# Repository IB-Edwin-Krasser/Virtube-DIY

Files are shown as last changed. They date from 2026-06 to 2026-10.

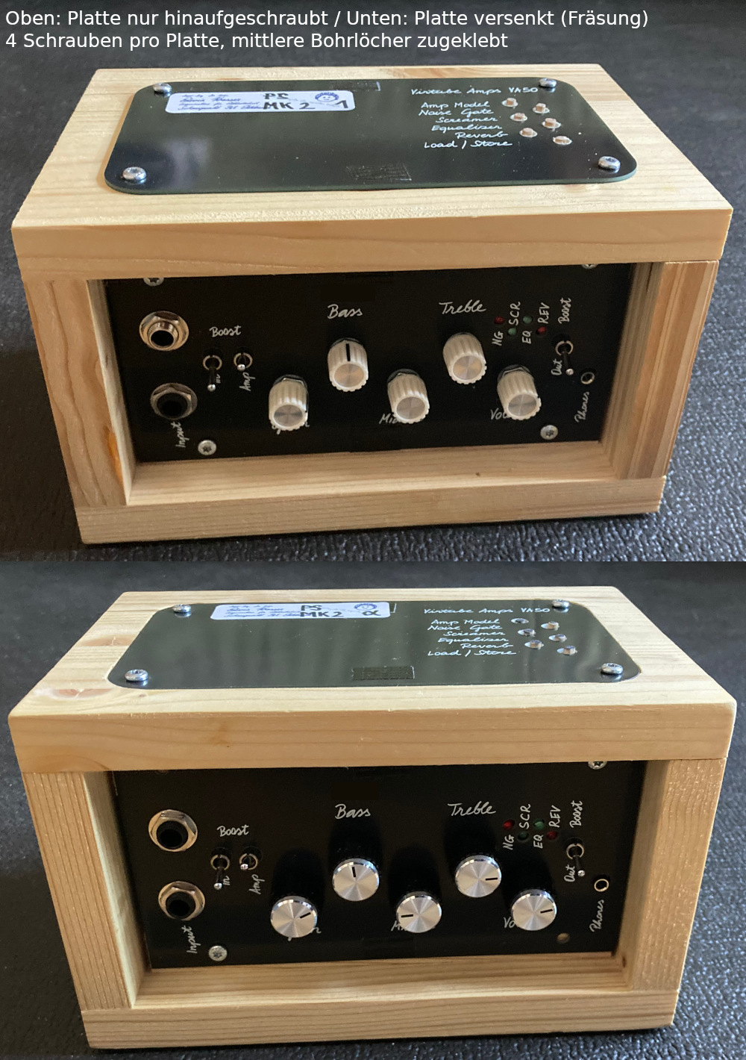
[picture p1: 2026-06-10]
fertigungsdaten/Foto2-Prototyp.JPG

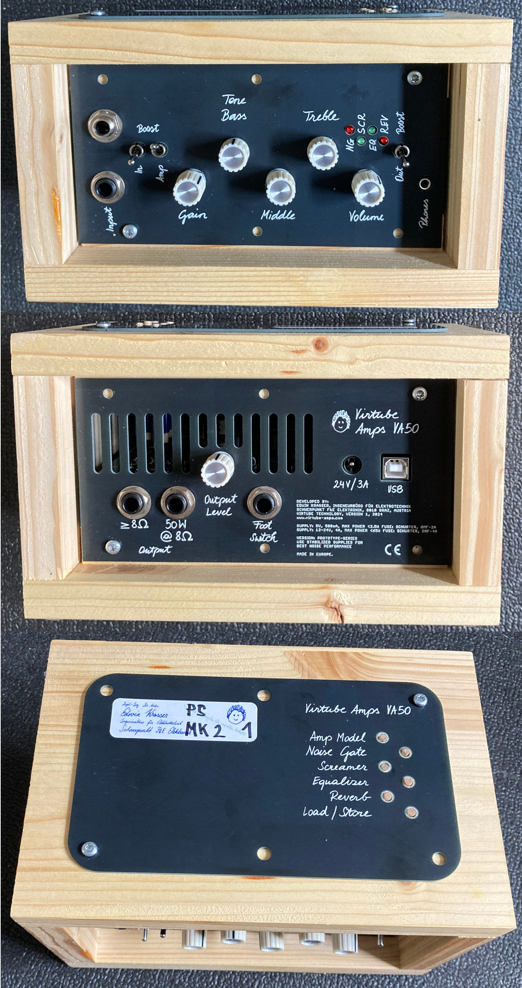
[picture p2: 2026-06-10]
fertigungsdaten/Foto1-Prototyp.JPG

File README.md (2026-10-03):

## readme.md: Virtube-DIY

AmpLightFront

"Virtube Amps VA50" – Virtueller Vollröhrenverstärker: So habe ich das "Kastl" genannt. Nun gebe ich die Fertigunsdaten der Hardware sowie das Software-Grundgerüst frei.

* ./brd: Schaltplan, Layout und Eagle-BRD-Datei.

* ./fertigungsdaten: Fertigungsdaten für Hauptprint und den Blenden, diverse Beschreibungen und Anleitungen.  
  *Anmerkung: Das so gefertigte Gerät ist von einem akkreditierten Testlabor auf alle CE-notwendigen Eigenschaften erfolgreich getestet worden.*

* ./Virtube-DIY: Code Composer Studio Projekt.
    * Framework und Treiber, jeder kann seinen Verstärker selbst programmieren.
    * Das gesamte Software-Framework ist Doxygen-dokumentiert.
    * Die Simulationen und Berechnungen der virtuellen Verstärker sind nicht Teil der Veröffentlichung.
    * Die vier Effekte (Noise Gate, Tube Screamer, Equalizer, Reverb) sind dabei, sowie die virtuelle Röhrenberechnung (mit einer Beispielberechnung in "amps.c"), viel Spaß damit!
    * Library-Dateien von TI sind aus lizenzrechtlicher Vorsicht nicht dabei, sehrwohl aber ein Verzeichnisbaum mit den benötigten Dateien (C2000Ware). Siehe: https://e2e.ti.com/support/microcontrollers/c2000-microcontrollers-group/c2000/f/c2000-microcontrollers-forum/1654050/tms320f28377s-c2000ware-license-and-public-dist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
    * Code-Stil-Beschreibung: siehe "C-CodingStyle.pdf"

* Lizenzinformationen zur Hardware:
    * CERN Open Hardware Licence Version 2 - Weakly Reciprocal (CERN-OHL-W v2)
    * Copyright © 2025 Edwin Krasser
    * This hardware design is released under the CERN-OHL-W v2 license with the following additional restriction:
    * Commercial use, production, sale, or incorporation into commercial products is explicitly prohibited without prior written permission from the author.
    * Contact Edwin Krasser for commercial licensing.
    * Gerber files, Board files (.brd) and BOM are provided for non-commercial use.
    * Schematic is provided as PDF only (not as editable source).

* Edwin Krasser, Ingenieurbüro für Elektrotechnik, Schwerpunkt F&E Elektronik.
* ib.ekrasser@gmail.com
* www.ib-ekrasser.at
* www.ib-ekrasser.at/virtube

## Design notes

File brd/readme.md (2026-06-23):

## License & Usage

This project is released under the **CERN-OHL-W v2** license with **non-commercial** restriction.

**What you may do:**
- Private use, education, research, non-profit projects
- Modify and build the hardware for yourself
- Share modified versions (under the same license)

**What you may NOT do:**
- Sell boards or kits
- Use the design in commercial products
- Distribute for commercial purposes

Schematic is provided as PDF only.  
Eagle board file (.brd) is provided for non-commercial reproduction.

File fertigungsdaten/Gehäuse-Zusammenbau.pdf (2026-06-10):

Gehäuse - Zusammenbau
1. Benötigte Teile, 18 mm Holz (Fichte)
- 2x 21x14 cm
- 2x 9x14 cm
- 1x 17x10 cm
- 2x 2x17 cm
2. 21x14 cm mit 9x14 cm Seitenteilen und zweimal 2x17 cm im Abstand von 2 cm zur Vorder-/Hinterkante verleimen.

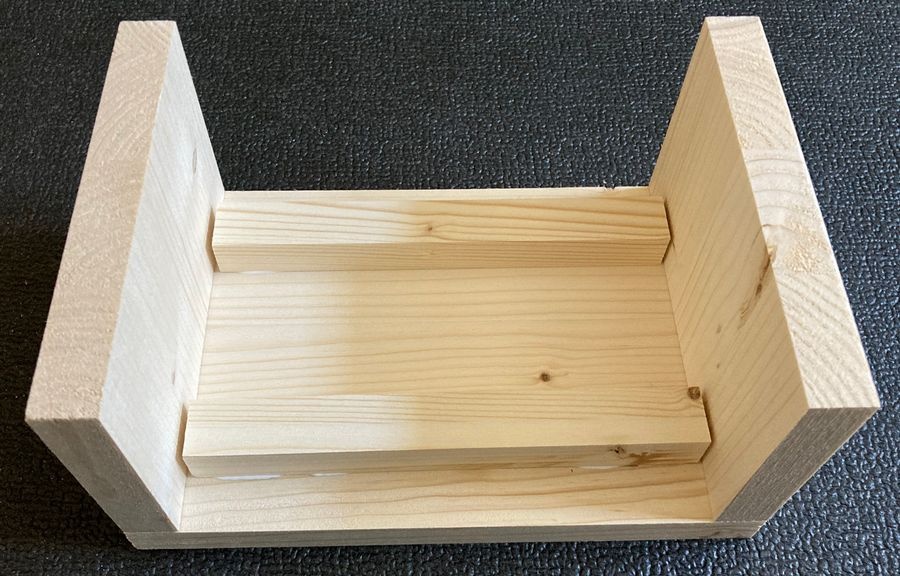
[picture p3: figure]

3. 21x14 cm (oben) fräsen (2 mm, damit die obere Abdeckung genau passt, oder auch nicht), mit 17x10 cm zusammenleimen und bohren

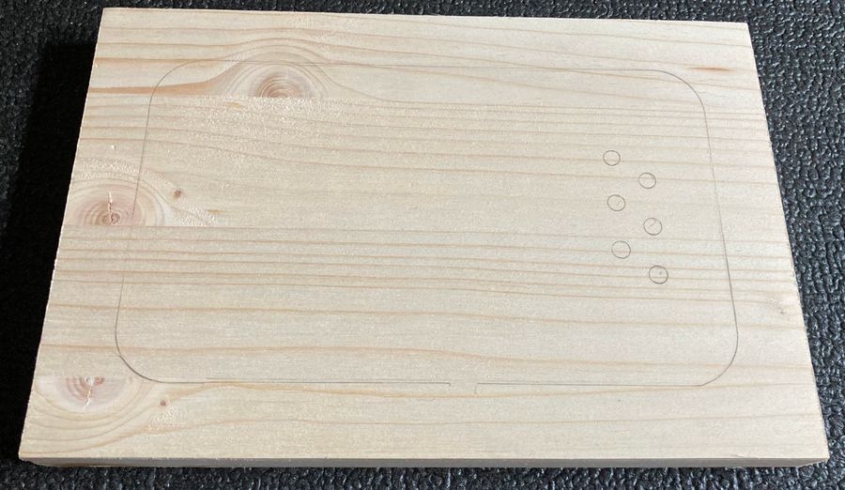
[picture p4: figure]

Hier nur gebohrt (4 mm), Position der Bohrlöcher: 40 bzw. 50 mm rechts, linke Reihe 58.75 mm, 73.75 mm (15 mm weiter), 88.75 (15 mm weiter), rechte Reihe 51.25, 66.25 und 81.25 mm. Bohrung mit gut 4 mm (eher 4.2 mm Bohrer?).

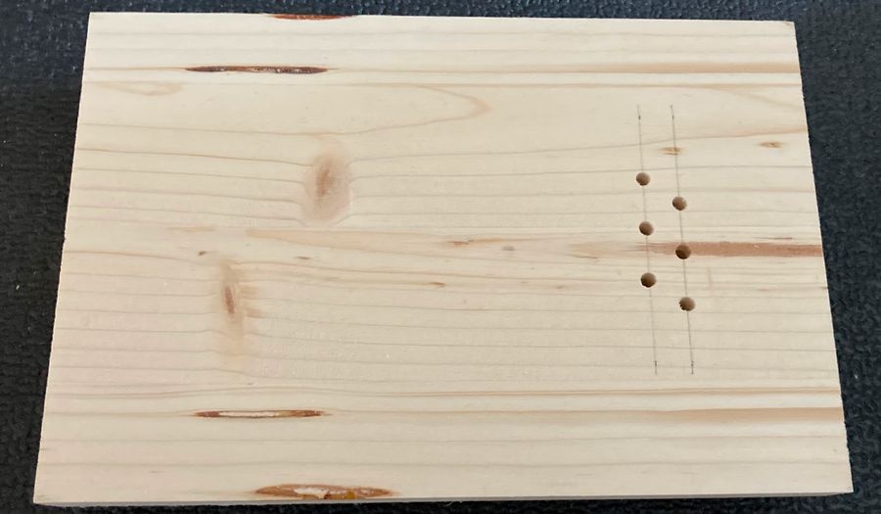
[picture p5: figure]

4. Gehäuse zusammenleimen

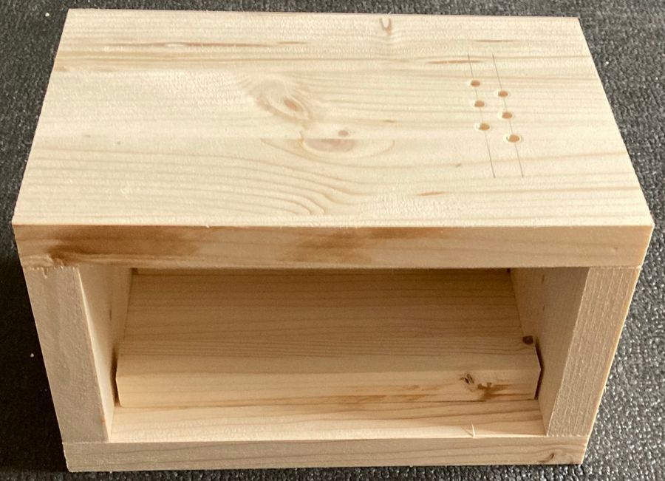
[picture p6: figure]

5. Kanten etwas abrunden? Dann ölen, lackieren oder was auch immer …
6. Stößel aus 4 mm Rundholz und Länge 60 mm (bzw. 62 mm wenn der obere Print hinaufgeschraubt ist) … an den Stößeln mit mindestens 40 mm Abstand von oben eine Verdickung anbringen (hier mit Isolierband)

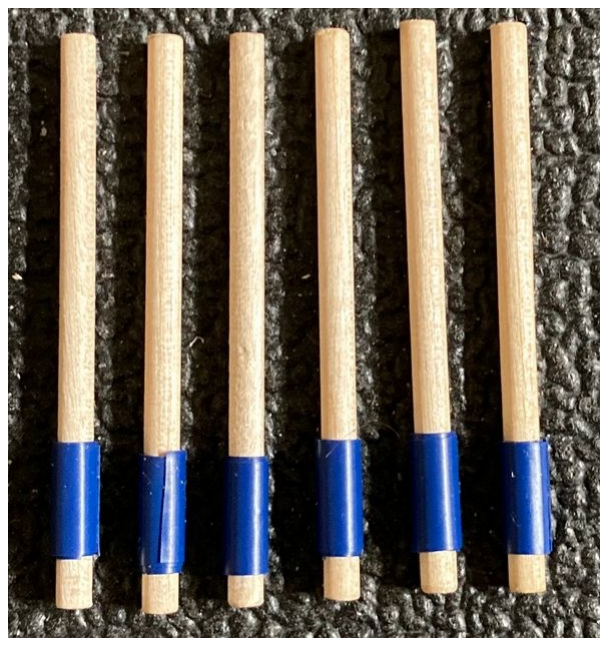
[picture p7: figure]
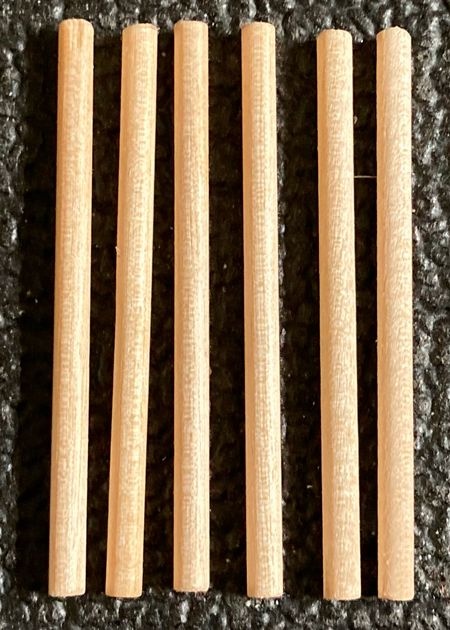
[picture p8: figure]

7. Stößel ins Gehäuse einsetzen, von innen (darum ist unten keine volle Platte, damit sich das mit der Länge der Stößel ausgeht)

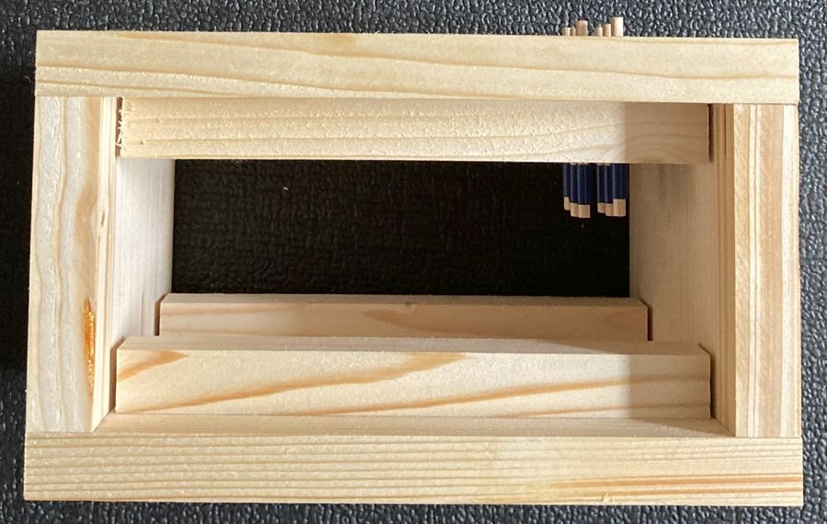
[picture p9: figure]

8. Zusammenbau
- Zuerst Front-Blende mit dem Print verschrauben, dann ins Gehäuse einsetzen …

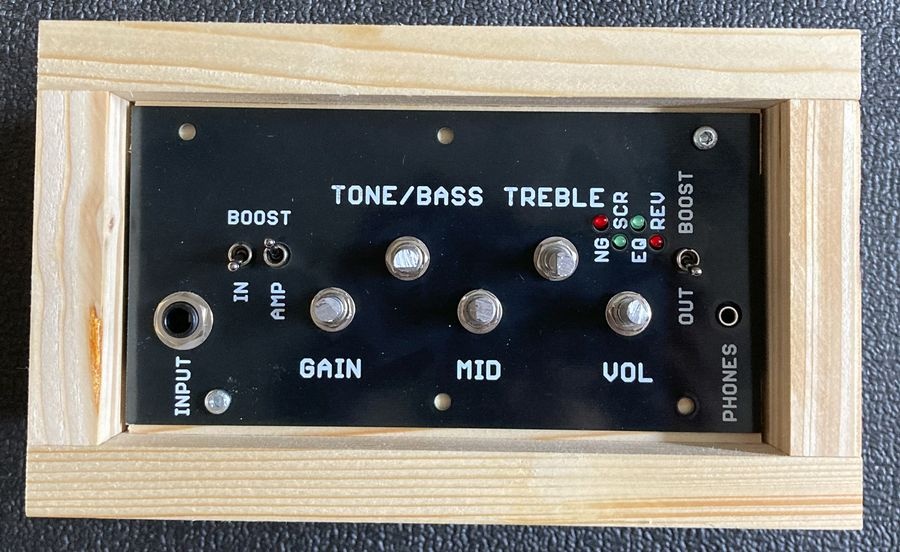
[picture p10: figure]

- Rückseite verschrauben …

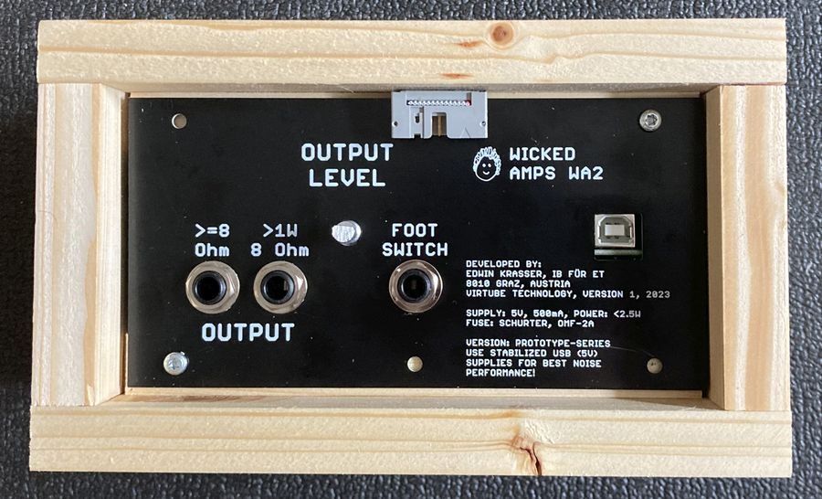
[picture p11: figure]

Anmerkung: Hier (Prototyp) ist auch der Debug-Stecker zu sehen. Der ist später natürlich nicht dabei.

- Obere Abdeckung anschrauben …

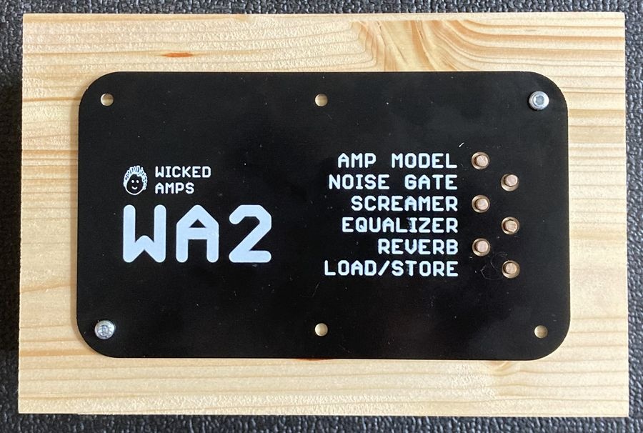
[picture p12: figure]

9. Abschließend: Poti-Knöpfe montieren. Bei den richtigen Potis müssten diese nur hinauf gesteckt werden (Riffelung statt glatt).

Anmerkung: Hier werden (Prototyp) nicht alle Schrauben verwendet, sondern immer nur zwei statt alle sechs. Das macht ein Zerlegen wieder einfacher.

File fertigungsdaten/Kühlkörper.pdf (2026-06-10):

Kühlkörper - Zusammenkleben

### 1. Vorbereitung

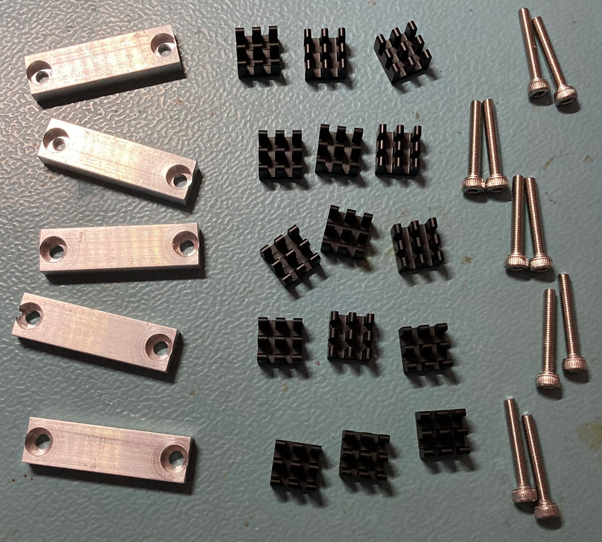
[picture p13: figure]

Pro Kühlkörper:

- Träger-Block
- 2x M3 Zylinderkopf-Schrauben, 20 mm Länge
- 3x 10x10mm Kühlkörper

HSB02-101007

Digi-Key-Teilenr. | 2223-HSB02-101007-ND
Hersteller | CUI Devices (https://www.digikey.at/de/supplier-centers/cui-devices)
Hersteller-
Teilenummer | HSB02-101007
Beschreibung | HEAT SINK, BGA, 10 X 10 X 7 MM

### 2. Zusammenbau

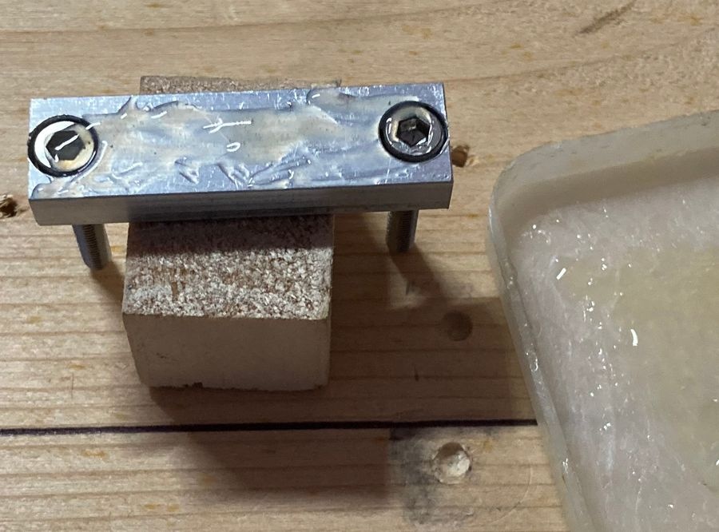
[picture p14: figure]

- Schrauben durchsteckern.

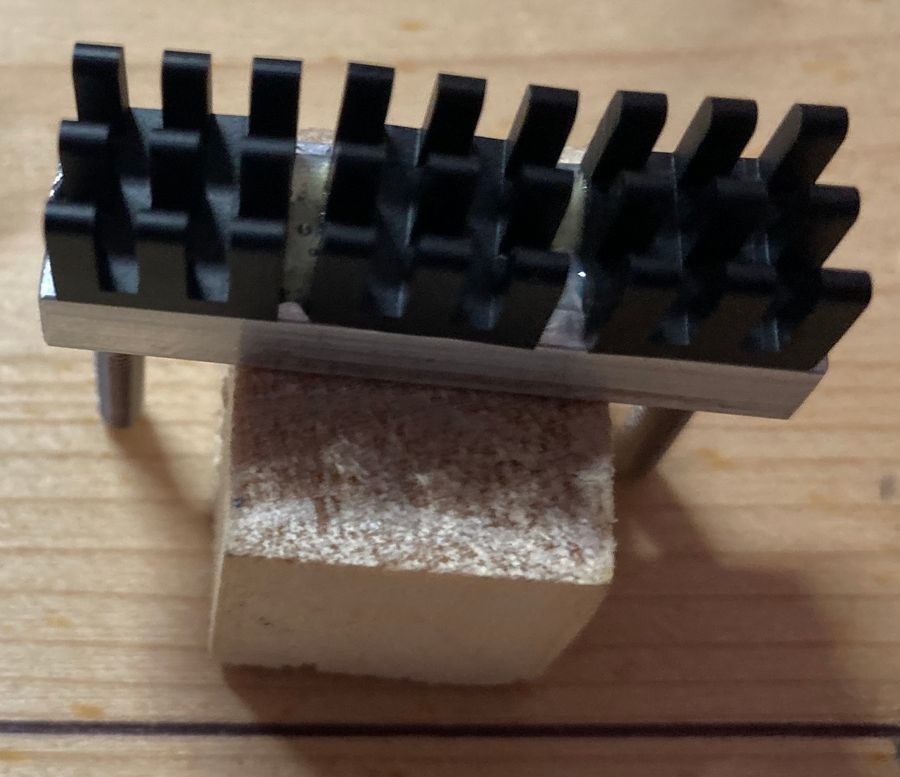
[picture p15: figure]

- Mit UHU Plus (Epoxidharz-Kleber) einstreichen.
- Die drei Kühlkörper aufsetzen.

### 3. Ab ins Backrohr

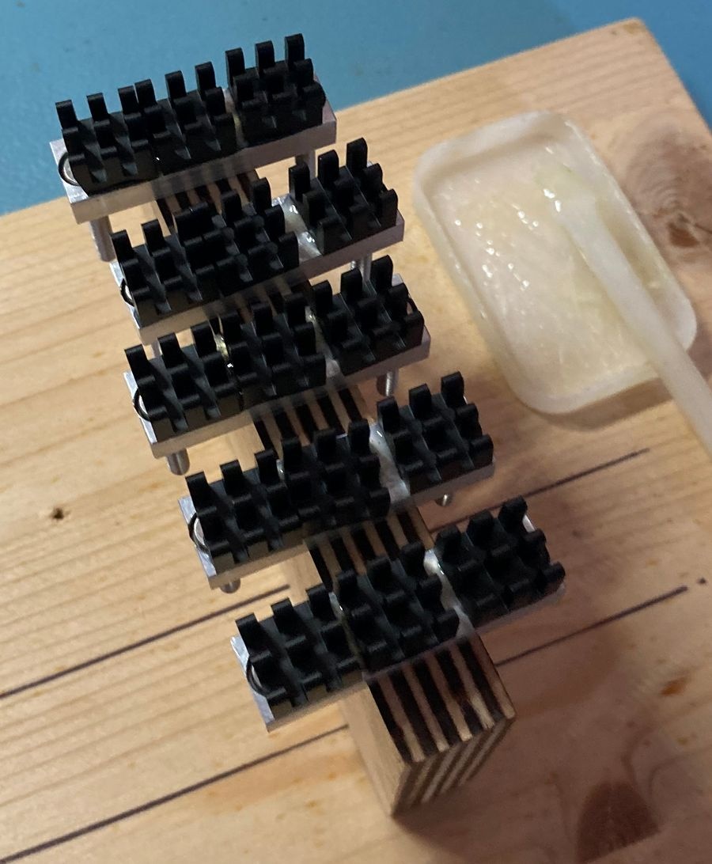
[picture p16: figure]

- Mehrere auf einem Holzstück reihen …
- Ab ins Backrohr: auf 100 °C aufheizen, abschalten, Kühlkörper ins Rohr und 45 Minuten „auskühlen lassen“

Kühlkörper - Einbau

### 1. Wärmeleitschaumstoff aufkleben

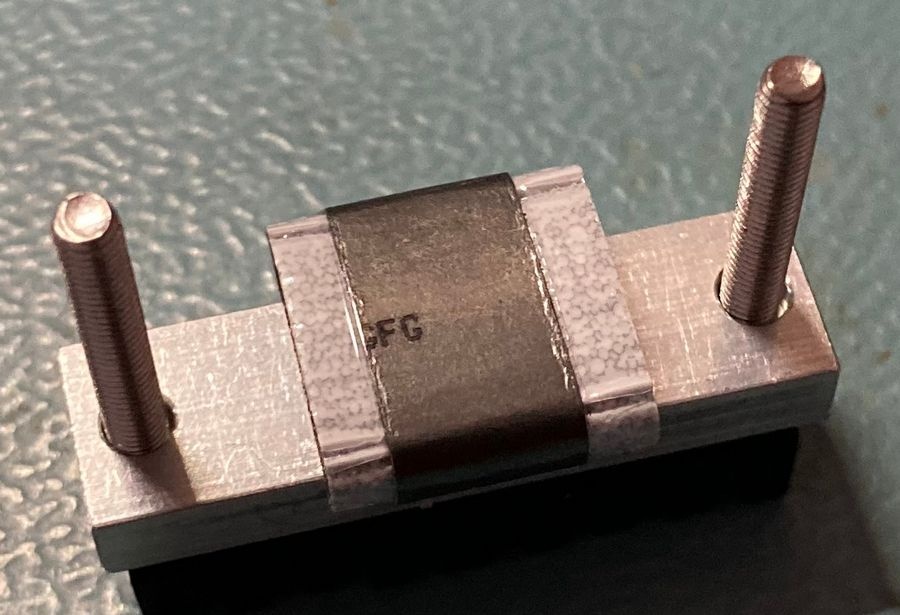
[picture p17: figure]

- Würth Elektronik: WE-TGFG Thermal Graphite Foam Gasket: 407150015050

### 2. Print: Kühlkörper-Schrauben durchstecken

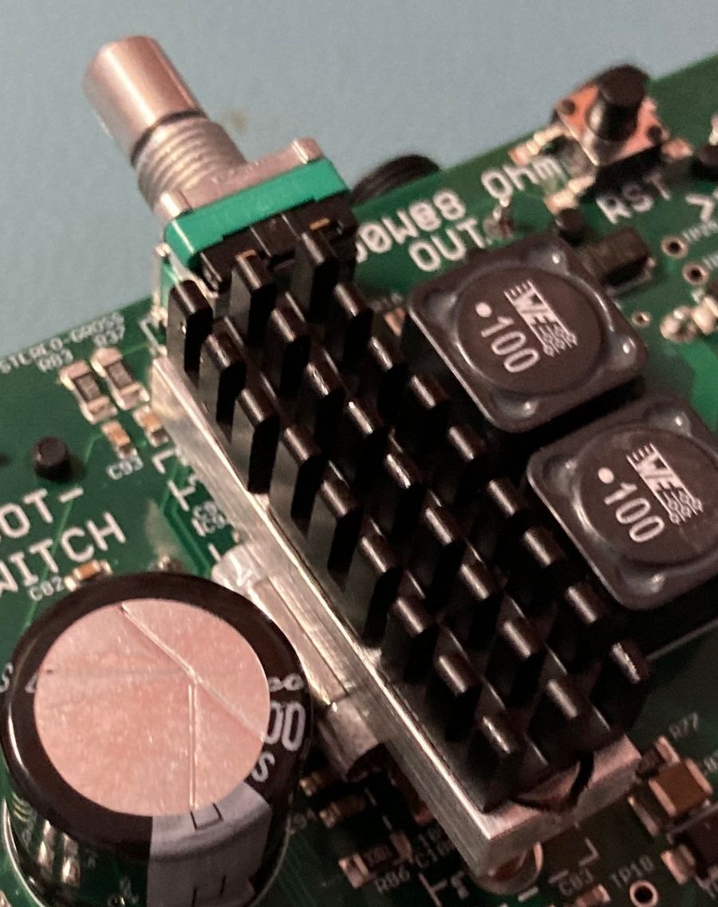
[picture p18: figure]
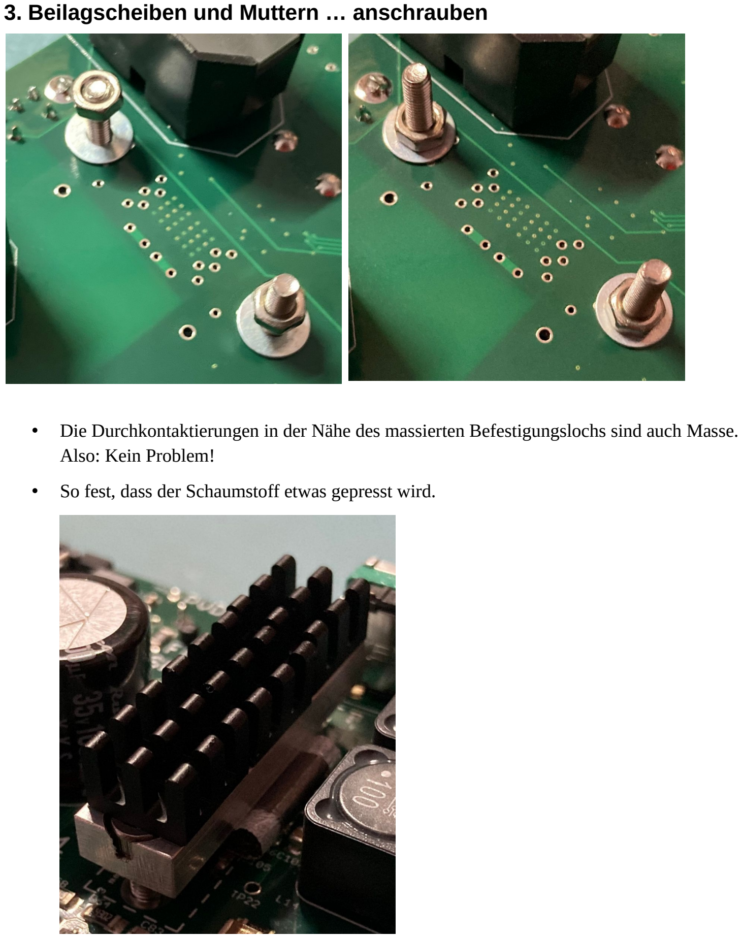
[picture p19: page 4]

### 3. Beilagscheiben und Muttern … anschrauben

- Die Durchkontaktierungen in der Nähe des massierten Befestigungslochs sind auch Masse. Also: Kein Problem!
- So fest, dass der Schaumstoff etwas gepresst wird.

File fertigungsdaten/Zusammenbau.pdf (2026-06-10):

Zusammenbau

### 1. Start: Elektronik – Frontblende – zweite Klinkenbuchse

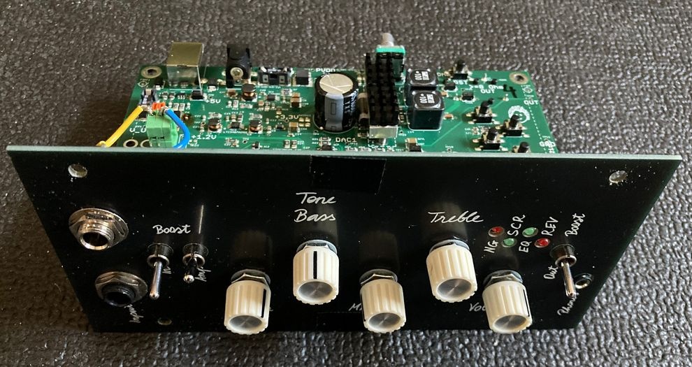
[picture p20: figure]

- Frontblende aufstecken

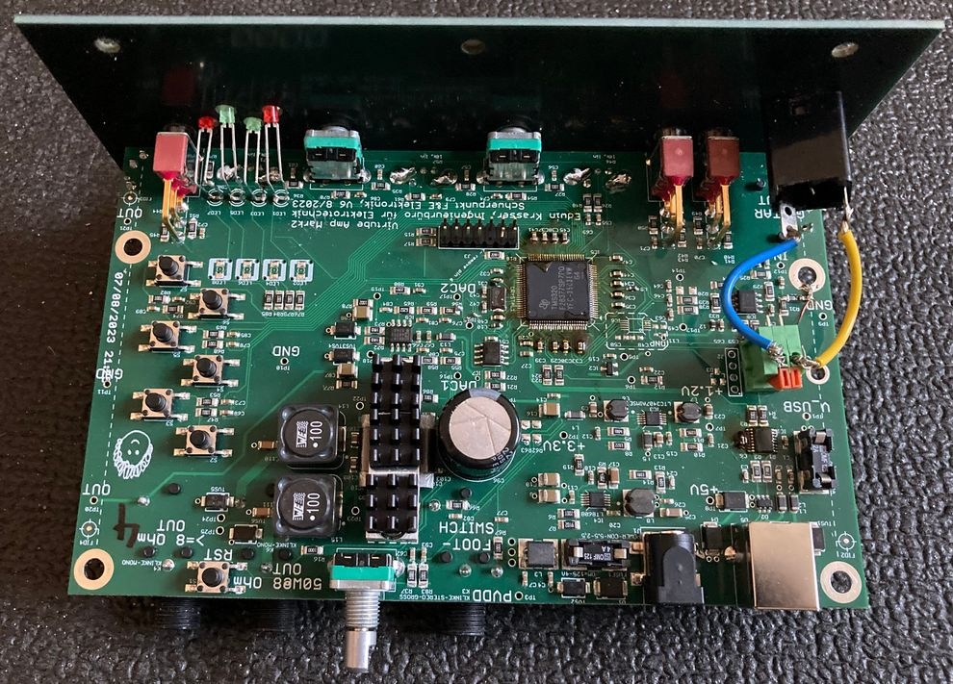
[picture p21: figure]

- Potis mit Beilage/Mutter fixieren (nicht zu fest, da sie etwas vom Rand entfernt sind, ist beim Redesign berichtigt)
- zweite Klinkenbuchse: Switchcraft Inc. 111X, DigiKey-Teilenr. SC2830-ND
- zweite Klinkenbuchse bei der Steckklemme anschließen (wird im Redesign etwas anders ausgerichtet sein, hier ist noch eine Bastellösung eingebaut, dann: näher der Klinkenbuchse/Vorderpanel … Signal, näher Rückwand: Ground).
- Kühlkörper montiert

### 2. Holzgehäuse vorbereiten

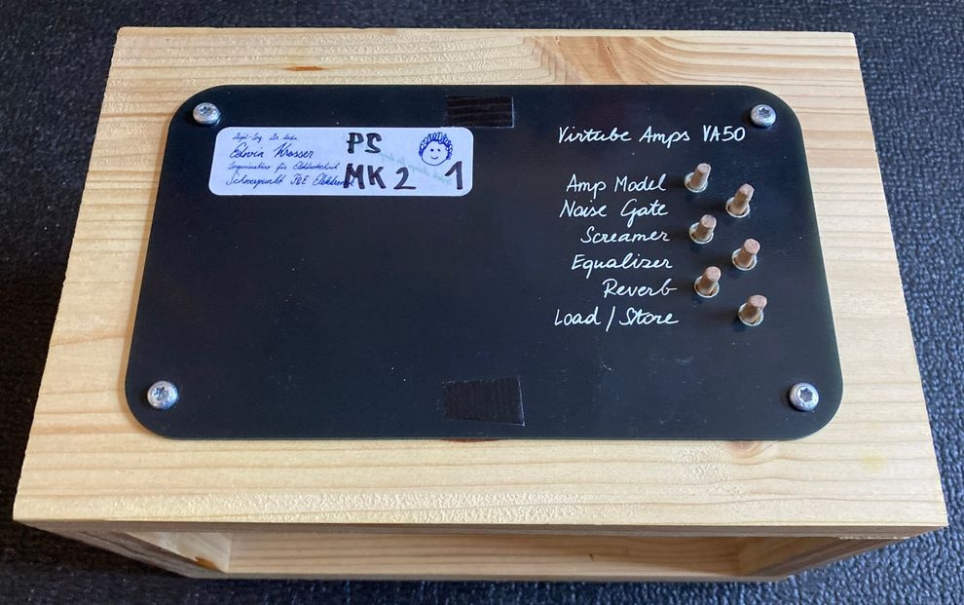
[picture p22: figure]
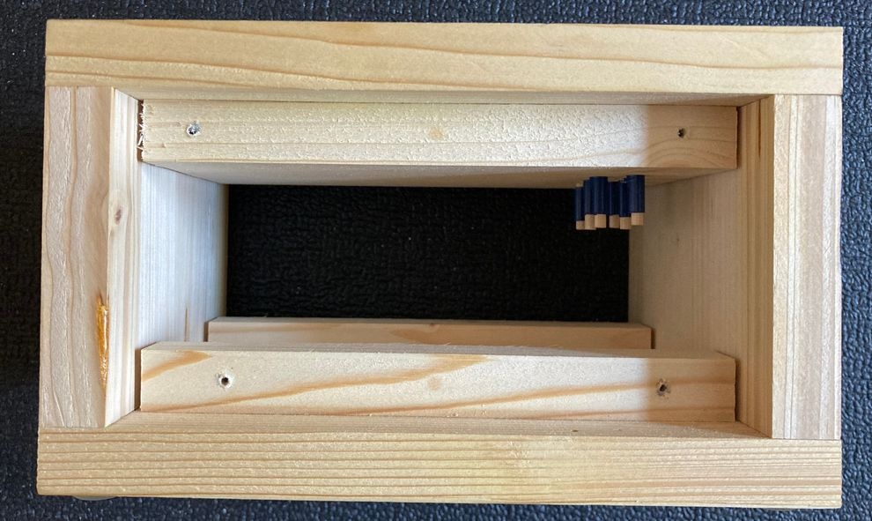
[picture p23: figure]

- Platte oben montieren (den Prototypen-Aufkleber gibt es später natürlich nicht)
- Tasten-Stößel durchstecken und nach oben, sodass sie oben etwas weiter heraus stehen
- Hier wäre es schön, wenn die obere Platte versenkt wäre, also diese 2 mm im Holz ausgefräst werden (wie bei diesem Prototypen).

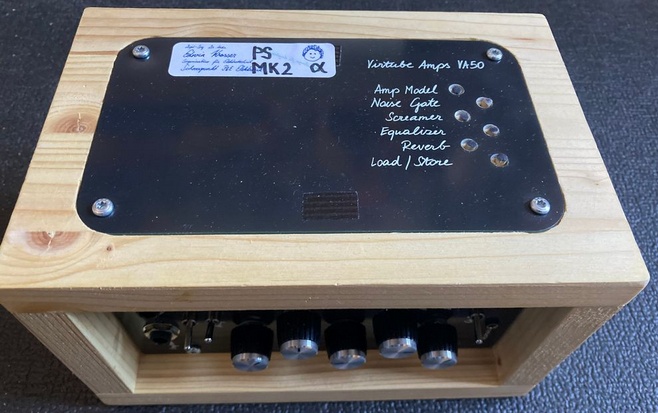
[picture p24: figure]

### 3. Zusammenbauen

- Elektronik mit Front einbauen (vier Schrauben)

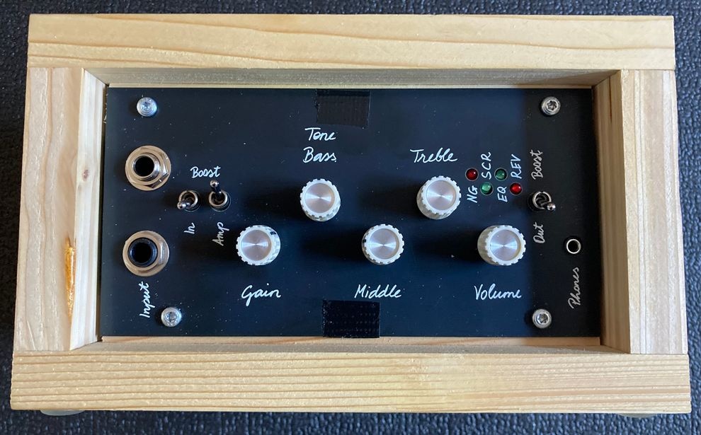
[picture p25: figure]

- Rückblende hinauf stecken, Beilagscheiben …

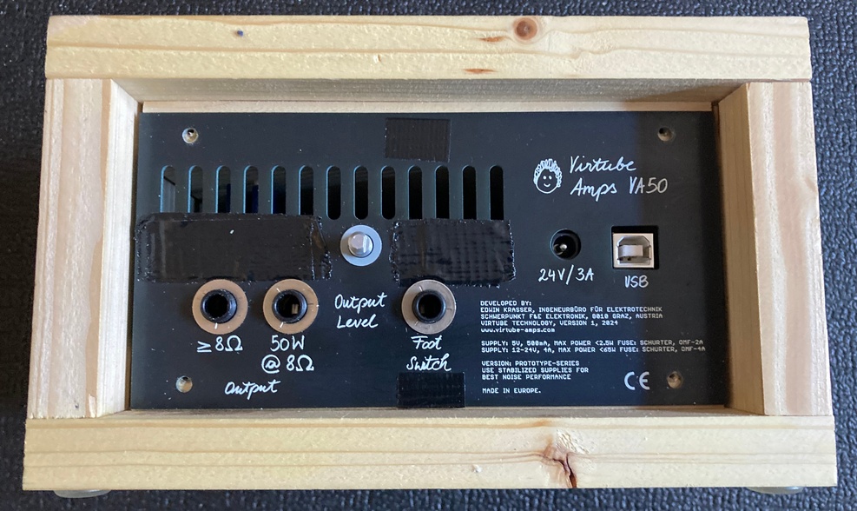
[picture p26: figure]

- Rückblende anschrauben, Potiknopf montieren


Anmerkungen …
- Auf diesen Blenden sind noch sechs Schraubbefestigungen vorgesehen, vier sollten auch reichen. Deshalb sind die mittleren Bohrlöcher zugeklebt.
- Die Lüftungschlitze (Fräsungen) in der Rückblende müssen etwas kürzer sein, darum sind sie mit Klebeband teilweise abgeklebt worden. Ist in den Dateien fü das endgültige Design eingepflegt.

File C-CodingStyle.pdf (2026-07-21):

Edwin Krasser
Ingenieurbüro für Elektrotechnik Schwerpunkt F&E Elektronik
8010 Graz - Pistotnikgasse 8/3

# Mikrocontroller: C-Coding Style

Dieses Dokument beschreibt den bevorzugten Coding-Stil für Mikrocontroller bei Programmen in der Programmiersprache C, also der in dieser Anwendung (fast) einzigen.

## Dateien - Module - Namen

1. Dateinamen sind grundsätzlich auf englisches Vokabular zurückzuführen. Wie alles andere auch.
2. Die Funktionen und Variablen inklusive deren Deklaration jeder einzelnen Gruppe (Modul) sind in einer Datei implementiert. Diese Datei trägt dann den Namen “module.c” und beinhaltet auch die Deklarationen, wodurch eine zusätzliche Header-Datei eingespart werden kann. Wenn nur der Header-Teil dieses Moduls eingebunden werden soll, muss vor dem “#include “module.c”” noch das Makro “HEADER_MODULE” definiert werden.
Anmerkung: Dies kann, wenn vom Kunden anders gewünscht, natürlich auch im klassischen Stil mit “.h”- und “.c”-Datei erfolgen.
3. Die Datei, welche das Hauptprogramm beinhaltet, heißt “main.c”.
4. Einzelne, benötigte Funktionen, welche kein eigenes Modul verlangen, werden in einem Modul für diverse Funktionalität zusammengefasst (zum Beispiel: “misc.c”).

## Deklarationen - Definitionen

1. Im Header-Teil erfolgen die Deklarationen der öffentlichen Komponenten in der Reihenfolge: Makros, Datentypen, Variablen, Funktionen.
Anmerkung: Wenn es sinnvoll ist, ein Makro kurz vor einer Variablen oder Funktion zu definieren, wird dies auch so gemacht.
2. Die öffentlichen Variablen und Funktionen eines Moduls beginnen immer mit einem Kürzel in Blockbuchstaben für das Modul gefolgt von ‘_’. Danach folgt der Name in Upper Camel Case. Beispiel: MOD_GetData(void), Kürzel “MOD_” für “module.c”
3. Dieses Kürzel sollte auf maximal vier Zeichen, vorzugsweise zwei oder drei, beschränkt sein. Anmerkung: Den kompletten Modulnamen auszuschreiben macht die Namen nur unnötig lang, denn da Mikrocontroller-Programme nicht aus hunderten Modulen bestehen, sollten Abkürzungen ausreichen.
4. Jede einzelne Komponente ist Doxygen-dokumentiert, egal ob öffentlich oder privat.
5. Private Variablen und Funktionen können auf das Modul-Kürzel zu Beginn verzichten. Das Modul-Kürzel wird manchmal trotzdem verwendet, vor allem dann, wenn Doppeldeutigkeiten im Debugger entstehen könnten, weil gleich benannte, private Variablen in mehreren Modulen existieren.
6. Die Namen von Strukturen, Unions und andere Datentypen haben kein zusätzliches Prä- oder Suffix.
Anmerkung: Es sollte in der Verwendung ohnehin klar sein worum es sich handelt. Wenn dies nicht so ist, sollte die Sinnhaftigkeit des Datentypen hinterfragt werden.
7. Elemente in Strukturen werden ohne beschreibenden Variablennamen benannt, solange die Bedeutung offensichtlich ist.

Stand Jänner 2023

Beispiel: Der Datentyp “Coordinate” ist eine Struktur und beinhaltet drei Variablen mit den Namen ‘x’, ‘y’ und ‘z’).

## Funktionen - Programmzeilen

1. Zu Beginn jeder Funktion werden alle darin verwendeten Variablen definiert. Definitionen innerhalb der Funktion werden ausnahmslos vermieden.
2. Danach folgt eine Leerzeile, nach der mit den Befehlen begonnen wird.
3. Auch wenn return keine Funktion ist, wird der Rückgabewert immer in Klammer gesetzt (wie es ganz alte Compiler früher verlangt haben).
4. Das Beginn-Symbol ‘{‘ wird in der nächsten Zeile mit gleichen Einrückung wie der Befehl bzw. Funktionsnamen in der Zeile davor geschrieben.
5. Der erste Befehl steht in derselben Zeile wie das ‘{‘-Zeichen.
6. Die Einrückung beträgt prinzipiell zwei Leerzeichen. Tabulatoren sind tabu.
7. Wenn Befehle trivial sind, können auch mehrere in einer Zeile stehen.
8. Zum Kommentieren wird grundsätzlich nur das Kommentar im C-Stil verwendet:
“/* blabla */” (Man denke an MISRA-C.)
9. Falls ein Kommentar im C++-Stil eingesetzt wird (“// blabla”), markiert das eine temporäre Zwischenlösung, die wieder bereinigt werden soll.

## Variablen - Zuweisungen - Operationen

1. Lokale Variablen in Funktionen, welche nur einen Buchstaben lang sind, werden, wenn sie mit dem einzelnen Buchstaben den Inhalt ausreichend genau beschreiben, verwendet. Zum Beispiel: ‘i’, ‘j’,’k’,’l’,’m’,’n’ für Indizes, Laufvariablen und Anzahl; ‘d’,’f’ für temporäre Fließkomma-Variablen; ‘x’,’y’,’z’ für kartesische Koordinaten; ‘c’ für ASCII-Zeichen bzw. ’s’ Zeichenketten, …
2. Einbuchstabige Variablen sind auch erlaubt, wenn der Geltungsbereich nur eine einfach überschaubare Anzahl von Zeilen beträgt.
Zum Beispiel: Kurze, überschaubare Funktionen, die nicht einmal einen halben Bildschirm lang sind.
3. Auf Datentypen wie uint16_t und ähnliche wird verzichtet, da diese ohne Syntax-Highlighting nur die Verständlichkeit vermindern. Stattdessen werden die Makros “i16” und “i32” verwendet, um je nach Zielsystem 16-Bit- und 32-Bit-Typen zu beschreiben. Die einzige Ausnahme ist, wenn Bibliotheksfunktionen anderer solche Typen verlangen.
4. Bei ganzzahligen Datentypen, deren Information in der Zahl steckt, werden vorzugsweise signed-Variablen benutzt. Unsigned-Variablen werden nur dann verwendet, wenn die Information in den einzelnen Bits steckt (zum Beispiel: Bitfelder, Farbwerte, …).
5. Die ungarische Notation wird nicht verwendet.
Anmerkung: Ungarische Notation ist höflich geschrieben sehr entbehrlich.
6. Für ganzzahligen Werte werden Variablen mit dem natürlichen Datentyp (Registerbreite des Mikrocontrollers) verwendet, also “int”.
Anmerkung: Ein Mikroprozessor sollte nicht zu kleineren Datentypen gezwungen werden, da dies in der Ausführungsgeschwindigkeit nicht von Vorteil ist und dabei zu keinem signifikanten Speichervorteil führt.
7. Angeblich der Lesbarkeit dienliche Leerzeichen zwischen Operationen und Zuweisungen werden nicht eingesetzt.
Anmerkung: Dadurch werden vor allem intensivere, mathematische Berechnungen deutlich länger und damit unübersichtlicher. Aber das ist Ansichtssache.

8. Bei nicht offensichtlichen Prioritäten von Operatoren wird lieber die eine oder andere Klammerung zu viel vorgenommen.

## Compiler

1. Warnungen werden grundsätzlich als Fehler betrachtet und sind somit nicht erlaubt.
2. Falls eine Warnung in einer Datei, die von einer Bibliothek kommt, entsteht, so ist diese zu akzeptieren.
3. Während der Entwicklung werden Compiler-Optimierungen nur beschränkt eingesetzt, da diese zu Debugging-Problemen führen können und werden.
4. Ziel der Entwicklung ist es ohnehin, ohne exzessives Optimieren ein gut funktionierendes Programm zu implementieren.

## Grundsätzliches zum Thema Zusammenarbeit

1. Bibliotheken und zugekaufter Quellcode werden nicht verändert.
Anmerkung: Dies rächt sich üblicherweise bei Updates dieser.
2. Falls das aus welchen Gründen auch immer notwendig wird, dann muss diese Veränderung im Code klar gekennzeichnet werden. Es ist auch zu empfehlen, dass diese Veränderungen an den Lieferanten weitergegeben werden bzw. sollten die gewünschten Anpassungen vom Lieferanten selbst durchgeführt werden.
3. Beleidigungen in Kommentaren im Quellcode oder Versionsverwaltungssystem sind zu unterlassen.
4. Andererseits darf man auch die Berichtigung eines Fehlers bzw. den Hinweis auf einen durch eine andere Person nicht als persönlichen Angriff betrachten.
5. Auch wenn man zusammenarbeitet, ein Herumpfuschen im Quellcode des anderen zur gefühlten Behübschung oder Verbesserung (vor allem in getesteten, stabil funktionierenden Programmteilen), bleibt ein Herumpfuschen.
6. Das Herauslöschen des tatsächlichen Autors, Veränderung des Coding-Stils mit nachträglichem eigenem Eintragen als Autor ist eine äußerst fragwürdige und verwerfliche Vorgangsweise.
7. Zusammengefasst sollte es einen gegenseitigen Respekt vor der Arbeit und des Stils des anderen geben.

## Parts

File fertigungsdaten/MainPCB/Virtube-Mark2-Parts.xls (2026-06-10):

 |  |  |  | Resistors: E24, 1206 1% Ceramic capacitors: X7R (or X5R), 50V +/-10% >=10 uF ... +/-20% allowed <=1 nF or value with '*' ... C0G
Part | Value | Device | Package | Description | DNP | MF | MPN | MPN2
IC2 | ADR381 | LT1460KCS3-2.5 | SOT23 |  |  | AnalogDevices | ADR381ARTZ
IC3 | LTC3407AIMSE-2 | LTC3407AIMSE-2 | MSOP10+PAD | LTC3407A-2 Dual Synchronous 800mA, 2.25MHz Step-Down DC/DC Regulator |  | AnalogDevices | LTC3407AIMSE-2#PBF
IC4 | LT8608 | LT8608 | MSOP10+PAD | 42V, 1.5A Synchronous Step-Down Regulator with 2.5μA Quiescent Current |  | AnalogDevices | LT8608IMSE
IC8 | AD8606 | 2AMP_P8+4-AD8606D | SO08 | OP AMP |  | AnalogDevices | AD8606ARZ
IC9 | AD8616 | 2AMP_P8+4-AD8606D | SO08 | OP AMP |  | AnalogDevices | AD8616ARZ
R49 | 10k, lin | R-POT1-KEY | R-POT1-KEY | Potentiometer, einfach |  | Bourns | PRS11R-215F-S103B1
R55 | 10k, lin | R-POT1-KEY | R-POT1-KEY | Potentiometer, einfach |  | Bourns | PRS11R-215F-S103B1
R60 | 10k, lin | R-POT1-KEY | R-POT1-KEY | Potentiometer, einfach |  | Bourns | PRS11R-215F-S103B1
R71 | 10k, lin | R-POT1-KEY | R-POT1-KEY | Potentiometer, einfach |  | Bourns | PRS11R-215F-S103B1
R74 | 10k, lin | R-POT1-KEY | R-POT1-KEY | Potentiometer, einfach |  | Bourns | PRS11R-215F-S103B1
R84 | 10k, lin | R-POT1-KEY | R-POT1-KEY | Potentiometer, einfach |  | Bourns | PRS11R-215F-S103B1
SW1 | SPDT | SPDT | SPDT-KIPPSCHALTER | SPDT-Kippschalter |  | C&K | 7101SY9AV2BE
SW2 | SPDT | SPDT | SPDT-KIPPSCHALTER | SPDT-Kippschalter |  | C&K | 7101SY9AV2BE
SW3 | SPDT | SPDT | SPDT-KIPPSCHALTER | SPDT-Kippschalter |  | C&K | 7101SY9AV2BE
K5 | KLINKE-STEREO-KLEIN | KLINKE-STEREO-KLEIN | KLINKE-KLEIN-STEREO |  |  | CUI | SJ1-3533NG
J1 | POWER-CON-5.5-2.5 | POWER-CON-5.5-2.5 | POWER-CON-2.5-5.5 | Power Connector 5.5/2.5 mm |  | CUI Devices | PJ-002BH-SMT-TR
TVS1 | SMAJ5.0A | TVS-UNI-SMA | SMA-DO214 |  |  | Diodes | SMAJ5.0AQ-13-F
TVS3 | SMAJ5.0A | TVS-UNI-SMA | SMA-DO214 |  |  | Diodes | SMAJ5.0AQ-13-F
TVS4 | SMAJ5.0A | TVS-UNI-SMA | SMA-DO214 |  |  | Diodes | SMAJ5.0AQ-13-F
IC1 | FT230XS | FT230XS | SSOP16 | USB to BASIC UART IC |  | FTDI | FT230XS
LED1 | ROT | LED3MM | LED3MM | LED |  | LiteOn | LTL-4221NLC
LED3 | GRÜN | LED3MM | LED3MM | LED |  | LiteOn | LTL-4231NLC
LED5 | GRÜN | LED3MM | LED3MM | LED |  | LiteOn | LTL-4231NLC
LED7 | ROT | LED3MM | LED3MM | LED |  | LiteOn | LTL-4221NLC
IC7 | 24AA64-I/SN | EEPROM_I2C | SO08 | I2C EEPROM |  | Microchip | 24AA64-I/SN
CRYSTAL1 | NX5032GA-10M | CRYSTAL5032 | CRYSTAL5032 | crystal |  | NDKAmerica | NX5032GA-10.000M-STD-CSU-1
D1 | SK54BL | DIODE-SCHOTTKY-SMB | SMB-CASE403A03 | Schottky Diode |  | Panjit International Inc. | SK54BL_R1_00001
C103 | 1000uF, 35V | CPOL-EUE7.5-16 | E7,5-16 | POLARIZED CAPACITOR, European symbol |  | Rubycon | 35YXS1000MEFC16X16
FUSE2 | OMx125-2A | FUSE-OMH125 | OMH125 | Fuse |  | SCHURTER | 0031.7701.11 | 3404.0012.11
FUSE1 | OMx125-4A | FUSE-OMH125 | OMH125 | Fuse |  | SCHURTER | 0031.7701.11 | 3404.0016.11
S2 | LSH_SCHURTER | LSH_SCHURTER | LSH_SCHURTER |  |  | Schurter | 1301.9316
S3 | LSH_SCHURTER | LSH_SCHURTER | LSH_SCHURTER |  |  | Schurter | 1301.9316
S4 | LSH_SCHURTER | LSH_SCHURTER | LSH_SCHURTER |  |  | Schurter | 1301.9316
S5 | LSH_SCHURTER | LSH_SCHURTER | LSH_SCHURTER |  |  | Schurter | 1301.9316
S6 | LSH_SCHURTER | LSH_SCHURTER | LSH_SCHURTER |  |  | Schurter | 1301.9316
S7 | LSH_SCHURTER | LSH_SCHURTER | LSH_SCHURTER |  |  | Schurter | 1301.9316
D2 | USBLC6-2 | USBLC6-2 | SOT23-6L | USBLC6-2 |  | ST | USBLC6-2SC6
K2 | KLINKE-MONO | KLINKE-MONO | KLINKE-GROSS-MONO | Klinke, mono, groß |  | Switchcraft | RN111PC
K3 | KLINKE-STEREO-GROSS | KLINKE-STEREO-GROSS | KLINKE-GROSS-STEREO |  |  | Switchcraft | RN112BPC
K4 | KLINKE-MONO | KLINKE-MONO | KLINKE-GROSS-MONO | Klinke, mono, groß |  | Switchcraft | RN111PC
K6 | KLINKE-MONO | KLINKE-MONO | KLINKE-GROSS-MONO | Klinke, mono, groß |  | Switchcraft | RN111PC
C16 | 100u | C-EUC1210 | C1210 | CAPACITOR, European symbol |  | TayioYuden | LMK325ABJ107MMHP
C91 | 100u | C-EUC1210 | C1210 | CAPACITOR, European symbol |  | TayioYuden | LMK325ABJ107MMHP
C92 | 100u | C-EUC1210 | C1210 | CAPACITOR, European symbol |  | TayioYuden | LMK325ABJ107MMHP
IC5 | TMS320F28377SPZP | TMS320F28377SPZP | PQFP100_THERMAL | TMS320F28377S DelfinoTM Microcontroller |  | TexasInstruments | TMS320F28377SPZP
IC10 | TAS5828M | TAS5828M | TSSOP32-TI-NO-TOP-STOP | 50-W Stereo, Digital Input, High Efficiency Closed-Loop Class-D Amplifier with Hybrid-Pro Algorithm |  | TexasInstruments | TAS5828MDADR
D4 | VS-10BQ040 | DIODE-SCHOTTKY-SMB | SMB-CASE403A03 | Schottky Diode |  | Vishay | VS-10BQ040-M3/5BT
D5 | VS-10BQ040 | DIODE-SCHOTTKY-SMB | SMB-CASE403A03 | Schottky Diode |  | Vishay | VS-10BQ040-M3/5BT
J3 | 61301421121 | 6130XX21121_61301421121 | 61301421121 | WR-PHD 2.54 mm THT Dual Pin Header |  | WürthElektronik | 61301421121
J4 | 691403900002B | 691403900002B | 691403900002B | WR-TBL Serie 4039 - 2.54 mm Screwless Vertical Entry |  | WürthElektronik | 691403900002B
K1 | K_USB | 61400416121 | 61400416121 | WR-COM Horizontal USB Type B=>Code : Con_I-O_COM_USB-2.0_B_61400416121 |  | WürthElektronik | 61400416121
L1 | 600@100M,2A | WE-CBF_1206 | WE-CBF_1206(W=4.2) | WE-CBF SMD EMI Suppression Ferrite Bead |  | WürthElektronik | 74279218
L2 | 600@100M,2A | WE-CBF_1206 | WE-CBF_1206(W=4.2) | WE-CBF SMD EMI Suppression Ferrite Bead |  | WürthElektronik | 74279218
L3 | 416Ohm@100MHz | WE-SUKW_7427511 | WE-SUKW_7427511 | WE-SUKW SMT EMI Suppression 5-Hole Ferrite Bead |  | WürthElektronik | 7427511
L4 | 600@100M,2A | WE-CBF_1206 | WE-CBF_1206(W=4.2) | WE-CBF SMD EMI Suppression Ferrite Bead |  | WürthElektronik | 74279218
L5 | 600@100M,2A | WE-CBF_1206 | WE-CBF_1206(W=4.2) | WE-CBF SMD EMI Suppression Ferrite Bead |  | WürthElektronik | 74279218
L6 | 4.7uH | WE-PD2_4532_744773047 | WE-PD2_4532 | WE-PD2 SMT Power Inductor |  | WürthElektronik | 744773047
L7 | 4.7uH | WE-PD2_4532_744773047 | WE-PD2_4532 | WE-PD2 SMT Power Inductor |  | WürthElektronik | 744773047
L8 | 10uH | WE-PD2_5848_74477410 | WE-PD2_5848 | WE-PD2 SMT Power Inductor |  | WürthElektronik | 74477410
L9 | 1k@100M | WE-CBF_0603 | WE-CBF_0603(W=2.6) | WE-CBF SMD EMI Suppression Ferrite Bead |  | WürthElektronik | 74279266
L10 | 1k@100M | WE-CBF_0603 | WE-CBF_0603(W=2.6) | WE-CBF SMD EMI Suppression Ferrite Bead |  | WürthElektronik | 74279266
L12 | 1k@100M | WE-CBF_0603 | WE-CBF_0603(W=2.6) | WE-CBF SMD EMI Suppression Ferrite Bead |  | WürthElektronik | 74279266
L13 | 600@100M,2A | WE-CBF_1206 | WE-CBF_1206(W=4.2) | WE-CBF SMD EMI Suppression Ferrite Bead |  | WürthElektronik | 74279218
L14 | 10uH | WE-PD_1210_7447709100 | WE-PD_1210 | WE-PD SMT Power Inductor |  | WürthElektronik | 7447709100
L15 | 10uH | WE-PD_1210_7447709100 | WE-PD_1210 | WE-PD SMT Power Inductor |  | WürthElektronik | 7447709100
TVS2 | SMAJ33A | TVS-UNI-SMA | SMA-DO214 |  |  | WürthElektronik | SMAJ33A
TVS5 | SMAJ33A | TVS-UNI-SMA | SMA-DO214 |  |  | WürthElektronik | SMAJ33A
TVS6 | SMAJ33A | TVS-UNI-SMA | SMA-DO214 |  |  | WürthElektronik | SMAJ33A
C1 | 100n | C-EUC0603 | C0603 | CAPACITOR, European symbol
C2 | 47p | C-EUC0603 | C0603 | CAPACITOR, European symbol
C3 | 47p | C-EUC0603 | C0603 | CAPACITOR, European symbol
C4 | 10n | C-EUC0603 | C0603 | CAPACITOR, European symbol
C5 | 100n | C-EUC0603 | C0603 | CAPACITOR, European symbol
C6 | 100n | C-EUC0603 | C0603 | CAPACITOR, European symbol
C7 | 10n | C-EUC0603 | C0603 | CAPACITOR, European symbol
C8 | 10u, 50V | C-EUC1210 | C1210 | CAPACITOR, European symbol
C9 | 10u, 16V | C-EUC0805 | C0805 | CAPACITOR, European symbol
C10 | 10u, 50V | C-EUC1210 | C1210 | CAPACITOR, European symbol
C11 | 100n | C-EUC0603 | C0603 | CAPACITOR, European symbol
C12 | 22p | C-EUC0603 | C0603 | CAPACITOR, European symbol
C13 | 10u, 16V | C-EUC0805 | C0805 | CAPACITOR, European symbol
C14 | 100n | C-EUC0603 | C0603 | CAPACITOR, European symbol
C15 | 100n | C-EUC0603 | C0603 | CAPACITOR, European symbol
C17 | 10u | C-EUC1206 | C1206 | CAPACITOR, European symbol
C18 | 100n | C-EUC0603 | C0603 | CAPACITOR, European symbol
C19 | 100n | C-EUC0603 | C0603 | CAPACITOR, European symbol
C20 | 100n | C-EUC0603 | C0603 | CAPACITOR, European symbol
C21 | 22p | C-EUC0603 | C0603 | CAPACITOR, European symbol
C22 | 1n | C-EUC0603 | C0603 | CAPACITOR, European symbol
C23 | 10u, 16V | C-EUC0805 | C0805 | CAPACITOR, European symbol
C24 | 10p | C-EUC0603 | C0603 | CAPACITOR, European symbol
C25 | 10u | C-EUC1206 | C1206 | CAPACITOR, European symbol
C26 | 100n | C-EUC0603 | C0603 | CAPACITOR, European symbol
C27 | 10u | C-EUC0603 | C0603 | CAPACITOR, European symbol
C28 | 100n | C-EUC0603 | C0603 | CAPACITOR, European symbol
C29 | 10u | C-EUC0603 | C0603 | CAPACITOR, European symbol
C30 | 100n | C-EUC0603 | C0603 | CAPACITOR, European symbol
C31 | 100n | C-EUC0603 | C0603 | CAPACITOR, European symbol
C32 | 100n | C-EUC0603 | C0603 | CAPACITOR, European symbol
C33 | 100n | C-EUC0603 | C0603 | CAPACITOR, European symbol
C34 | 10u | C-EUC0603 | C0603 | CAPACITOR, European symbol
C35 | 100n | C-EUC0603 | C0603 | CAPACITOR, European symbol
C36 | 100n | C-EUC0603 | C0603 | CAPACITOR, European symbol
C37 | 100n | C-EUC0603 | C0603 | CAPACITOR, European symbol
C38 | 10u | C-EUC0603 | C0603 | CAPACITOR, European symbol
C39 | 100n | C-EUC0603 | C0603 | CAPACITOR, European symbol
C40 | 100n | C-EUC0603 | C0603 | CAPACITOR, European symbol
C41 | 100n | C-EUC0603 | C0603 | CAPACITOR, European symbol
C42 | 22p | C-EUC0603 | C0603 | CAPACITOR, European symbol
C43 | 10n | C-EUC0603 | C0603 | CAPACITOR, European symbol
C44 | 22p | C-EUC0603 | C0603 | CAPACITOR, European symbol
C45 | 10u | C-EUC0603 | C0603 | CAPACITOR, European symbol
C46 | 10u | C-EUC0603 | C0603 | CAPACITOR, European symbol
C47 | 47p | C-EUC0603 | C0603 | CAPACITOR, European symbol
C48 | 10n | C-EUC0603 | C0603 | CAPACITOR, European symbol
C52 | 100n | C-EUC0603 | C0603 | CAPACITOR, European symbol
C53 | 1u | C-EUC0603 | C0603 | CAPACITOR, European symbol
C54 | 100p | C-EUC0603 | C0603 | CAPACITOR, European symbol
C55 | 470p | C-EUC0603 | C0603 | CAPACITOR, European symbol
C56 | 1u | C-EUC0603 | C0603 | CAPACITOR, European symbol
C57 | 10n | C-EUC0603 | C0603 | CAPACITOR, European symbol
C58 | 10n | C-EUC0603 | C0603 | CAPACITOR, European symbol
C59 | 10n | C-EUC0603 | C0603 | CAPACITOR, European symbol
C60 | 100p | C-EUC0603 | C0603 | CAPACITOR, European symbol
C61 | 100p | C-EUC0603 | C0603 | CAPACITOR, European symbol
C62 | 1u | C-EUC0603 | C0603 | CAPACITOR, European symbol
C63 | 10n | C-EUC0603 | C0603 | CAPACITOR, European symbol
C64 | 10n | C-EUC0603 | C0603 | CAPACITOR, European symbol
C65 | 10n | C-EUC0603 | C0603 | CAPACITOR, European symbol
C66 | 100p | C-EUC0603 | C0603 | CAPACITOR, European symbol
C67 | 100p | C-EUC0603 | C0603 | CAPACITOR, European symbol
C68 | 100n | C-EUC0603 | C0603 | CAPACITOR, European symbol
C69 | 100n | C-EUC0603 | C0603 | CAPACITOR, European symbol
C70 | 10u | C-EUC0603 | C0603 | CAPACITOR, European symbol
C71 | 10n | C-EUC0603 | C0603 | CAPACITOR, European symbol
C72 | 10n | C-EUC0603 | C0603 | CAPACITOR, European symbol
C73 | 10n | C-EUC0603 | C0603 | CAPACITOR, European symbol
C74 | 10n | C-EUC0603 | C0603 | CAPACITOR, European symbol
C75 | 10n | C-EUC0603 | C0603 | CAPACITOR, European symbol
C76 | 10n | C-EUC0603 | C0603 | CAPACITOR, European symbol
C77 | 10n | C-EUC0603 | C0603 | CAPACITOR, European symbol
C78 | 1n | C-EUC0603 | C0603 | CAPACITOR, European symbol
C79 | 1n | C-EUC0603 | C0603 | CAPACITOR, European symbol
C80 | 10n | C-EUC0603 | C0603 | CAPACITOR, European symbol
C81 | 10n | C-EUC0603 | C0603 | CAPACITOR, European symbol
C82 | 10n | C-EUC0603 | C0603 | CAPACITOR, European symbol
C83 | 1n | C-EUC0603 | C0603 | CAPACITOR, European symbol
C84 | 1n | C-EUC0603 | C0603 | CAPACITOR, European symbol
C85 | 10n | C-EUC0603 | C0603 | CAPACITOR, European symbol
C86 | 100p | C-EUC0603 | C0603 | CAPACITOR, European symbol
C87 | 100p | C-EUC0603 | C0603 | CAPACITOR, European symbol
C88 | 10n | C-EUC0603 | C0603 | CAPACITOR, European symbol
C89 | 10n | C-EUC0603 | C0603 | CAPACITOR, European symbol
C90 | 1n | C-EUC0603 | C0603 | CAPACITOR, European symbol
C93 | 10n | C-EUC0603 | C0603 | CAPACITOR, European symbol
C94 | 10n | C-EUC0603 | C0603 | CAPACITOR, European symbol
C95 | 1n | C-EUC0603 | C0603 | CAPACITOR, European symbol
C96 | 10u | C-EUC0603 | C0603 | CAPACITOR, European symbol
C97 | 1n | C-EUC0603 | C0603 | CAPACITOR, European symbol
C98 | 10n | C-EUC0603 | C0603 | CAPACITOR, European symbol
C99 | 10n | C-EUC0603 | C0603 | CAPACITOR, European symbol
C100 | 1n | C-EUC0603 | C0603 | CAPACITOR, European symbol
C101 | 10u | C-EUC0603 | C0603 | CAPACITOR, European symbol
C102 | 100n | C-EUC0603 | C0603 | CAPACITOR, European symbol
C104 | 10u, 50V | C-EUC1210 | C1210 | CAPACITOR, European symbol
C105 | 10u, 50V | C-EUC1210 | C1210 | CAPACITOR, European symbol
C106 | 100n | C-EUC0603 | C0603 | CAPACITOR, European symbol
C107 | 10u, 50V | C-EUC1210 | C1210 | CAPACITOR, European symbol
C108 | 1u | C-EUC0603 | C0603 | CAPACITOR, European symbol
C109 | 1u | C-EUC0603 | C0603 | CAPACITOR, European symbol
C110 | 1u | C-EUC0603 | C0603 | CAPACITOR, European symbol
C111 | 10u, 50V | C-EUC1210 | C1210 | CAPACITOR, European symbol
C112 | 100n | C-EUC0603 | C0603 | CAPACITOR, European symbol
C113 | 470n, 50V | C-EUC0805 | C0805 | CAPACITOR, European symbol
C114 | 470n, 50V | C-EUC0805 | C0805 | CAPACITOR, European symbol
C115 | 470n, 50V | C-EUC0805 | C0805 | CAPACITOR, European symbol
C116 | 470n, 50V | C-EUC0805 | C0805 | CAPACITOR, European symbol
C117 | 680n, 50V | C-EUC1206 | C1206 | CAPACITOR, European symbol
C118 | 680n, 50V | C-EUC1206 | C1206 | CAPACITOR, European symbol
R3 | 27 | R-EU_R1206 | R1206 | RESISTOR, European symbol
R4 | 27 | R-EU_R1206 | R1206 | RESISTOR, European symbol
R5 | 3.3k | R-EU_R1206 | R1206 | RESISTOR, European symbol
R6 | 3.3k | R-EU_R1206 | R1206 | RESISTOR, European symbol
R7 | 1Meg | R-EU_R1206 | R1206 | RESISTOR, European symbol
R8 | 180k | R-EU_R1206 | R1206 | RESISTOR, European symbol
R9 | 22k | R-EU_R1206 | R1206 | RESISTOR, European symbol
R10 | 220k | R-EU_R1206 | R1206 | RESISTOR, European symbol
R11 | 43k | R-EU_R1206 | R1206 | RESISTOR, European symbol
R12 | 560k | R-EU_R1206 | R1206 | RESISTOR, European symbol
R13 | 560k | R-EU_R1206 | R1206 | RESISTOR, European symbol
R14 | 10k | R-EU_R1206 | R1206 | RESISTOR, European symbol
R15 | 1Meg | R-EU_R1206 | R1206 | RESISTOR, European symbol
R16 | 180k | R-EU_R1206 | R1206 | RESISTOR, European symbol
R17 | 4.7k | R-EU_R1206 | R1206 | RESISTOR, European symbol
R19 | 4.7k | R-EU_R1206 | R1206 | RESISTOR, European symbol
R20 | 2.2k | R-EU_R1206 | R1206 | RESISTOR, European symbol
R21 | 100k | R-EU_R1206 | R1206 | RESISTOR, European symbol
R23 | 3.3k | R-EU_R1206 | R1206 | RESISTOR, European symbol
R24 | 3.3k | R-EU_R1206 | R1206 | RESISTOR, European symbol
R25 | 10k | R-EU_R1206 | R1206 | RESISTOR, European symbol
R26 | 10k | R-EU_R1206 | R1206 | RESISTOR, European symbol
R27 | 100k | R-EU_R1206 | R1206 | RESISTOR, European symbol
R28 | 1k | R-EU_R1206 | R1206 | RESISTOR, European symbol
R29 | 1k | R-EU_R1206 | R1206 | RESISTOR, European symbol
R30 | 1k | R-EU_R1206 | R1206 | RESISTOR, European symbol
R31 | 220k | R-EU_R1206 | R1206 | RESISTOR, European symbol
R32 | 100k | R-EU_R1206 | R1206 | RESISTOR, European symbol
R33 | 100k | R-EU_R1206 | R1206 | RESISTOR, European symbol
R34 | 100k | R-EU_R1206 | R1206 | RESISTOR, European symbol
R35 | 100k | R-EU_R1206 | R1206 | RESISTOR, European symbol
R36 | 10k | R-EU_R1206 | R1206 | RESISTOR, European symbol
R37 | 10k | R-EU_R1206 | R1206 | RESISTOR, European symbol
R38 | 1k | R-EU_R1206 | R1206 | RESISTOR, European symbol
R39 | 1k | R-EU_R1206 | R1206 | RESISTOR, European symbol
R40 | 1k | R-EU_R1206 | R1206 | RESISTOR, European symbol
R41 | 100 | R-EU_R1206 | R1206 | RESISTOR, European symbol
R42 | 100 | R-EU_R1206 | R1206 | RESISTOR, European symbol
R44 | 1k | R-EU_R1206 | R1206 | RESISTOR, European symbol
R46 | 1k | R-EU_R1206 | R1206 | RESISTOR, European symbol
R48 | 1k | R-EU_R1206 | R1206 | RESISTOR, European symbol
R50 | 1k | R-EU_R1206 | R1206 | RESISTOR, European symbol
R51 | 1k | R-EU_R1206 | R1206 | RESISTOR, European symbol
R52 | 1k | R-EU_R1206 | R1206 | RESISTOR, European symbol
R53 | 1k | R-EU_R1206 | R1206 | RESISTOR, European symbol
R54 | 1k | R-EU_R1206 | R1206 | RESISTOR, European symbol
R56 | 1k | R-EU_R1206 | R1206 | RESISTOR, European symbol
R57 | 1k | R-EU_R1206 | R1206 | RESISTOR, European symbol
R58 | 10k | R-EU_R1206 | R1206 | RESISTOR, European symbol
R59 | 22k | R-EU_R1206 | R1206 | RESISTOR, European symbol
R61 | 22k | R-EU_R1206 | R1206 | RESISTOR, European symbol
R62 | 43k | R-EU_R1206 | R1206 | RESISTOR, European symbol
R63 | 1k | R-EU_R1206 | R1206 | RESISTOR, European symbol
R64 | 1k | R-EU_R1206 | R1206 | RESISTOR, European symbol
R67 | 43k | R-EU_R1206 | R1206 | RESISTOR, European symbol
R68 | 68k | R-EU_R1206 | R1206 | RESISTOR, European symbol
R69 | 1k | R-EU_R1206 | R1206 | RESISTOR, European symbol
R70 | 1k | R-EU_R1206 | R1206 | RESISTOR, European symbol
R72 | 1k | R-EU_R1206 | R1206 | RESISTOR, European symbol
R73 | 1k | R-EU_R1206 | R1206 | RESISTOR, European symbol
R75 | 1 | R-EU_R1206 | R1206 | RESISTOR, European symbol
R76 | 1 | R-EU_R1206 | R1206 | RESISTOR, European symbol
R77 | 1k | R-EU_R1206 | R1206 | RESISTOR, European symbol
R78 | 1k | R-EU_R1206 | R1206 | RESISTOR, European symbol
R79 | 1k | R-EU_R1206 | R1206 | RESISTOR, European symbol
R80 | 10k | R-EU_R1206 | R1206 | RESISTOR, European symbol
R81 | 10k | R-EU_R1206 | R1206 | RESISTOR, European symbol
R82 | 1k | R-EU_R1206 | R1206 | RESISTOR, European symbol
R83 | 2.2k | R-EU_R1206 | R1206 | RESISTOR, European symbol
R85 | 1k | R-EU_R1206 | R1206 | RESISTOR, European symbol
R86 | 1k | R-EU_R1206 | R1206 | RESISTOR, European symbol
R87 | 1k | R-EU_R1206 | R1206 | RESISTOR, European symbol
R88 | 1k | R-EU_R1206 | R1206 | RESISTOR, European symbol
R89 | 3.3k | R-EU_R1206 | R1206 | RESISTOR, European symbol
S1 | LSH_SCHURTER | LSH_SCHURTER | LSH_SCHURTER |  | T | Schurter | 1301.9316
D3 | BAS70 | BAS70 | SOT23 | Silicon Schottky Diodes | T | Vishay | BAS70-00-E3-08
J2 | 61300411121 | 6130XX11121_61300411121 | 61300411121 | WR-PHD 2.54 mm THT Pin Header | T | WürthElektronik | 61300411121
L11 | 1k@100M | WE-CBF_0603 | WE-CBF_0603(W=2.6) | WE-CBF SMD EMI Suppression Ferrite Bead | T | WürthElektronik | 74279266
C49 | 10u | C-EUC0603 | C0603 | CAPACITOR, European symbol | T
C50 | 1u | C-EUC0603 | C0603 | CAPACITOR, European symbol | T
C51 | 1u | C-EUC0603 | C0603 | CAPACITOR, European symbol | T
CE1 | CE-MARKING | CE-MARKING | CE-5MM-MIN-SIZE | CE marking | T
FID1 | FIDUCIAL | FIDUCIAL | FIDUCIAL | Feducial | T
FID2 | FIDUCIAL | FIDUCIAL | FIDUCIAL | Feducial | T
FID3 | FIDUCIAL | FIDUCIAL | FIDUCIAL | Feducial | T
FID4 | FIDUCIAL | FIDUCIAL | FIDUCIAL | Feducial | T
IC6 | ADS8867IDGS | ADS886XDGS | VSSOP10 | ADS8866 16-bit, 100-kSPS, serial interface, micropower, miniature, single-ended input, SAR analog-to-digital converter | T
LED2 | nb | LEDSMT1206 | 1206 | LED | T
LED4 | nb | LEDSMT1206 | 1206 | LED | T
LED6 | nb | LEDSMT1206 | 1206 | LED | T
LED8 | nb | LEDSMT1206 | 1206 | LED | T
LOGO1 | LOGO1 | LOGO1 | LOGO1 | IBEK LOGO | T
LP1 | nb | LIGHTPIPE | LIGHTPIPE_3MM | Light Pipe | T
LP2 | nb | LIGHTPIPE | LIGHTPIPE_3MM | Light Pipe | T
LP3 | nb | LIGHTPIPE | LIGHTPIPE_3MM | Light Pipe | T
LP4 | nb | LIGHTPIPE | LIGHTPIPE_3MM | Light Pipe | T
PCB1 | PCB-160X100-ALT1 | PCB-160X100-ALT1 | PCB-160X100-4-ALT1 | PCB with mounting holes | T
R1 | 0 | R-EU_R1206 | R1206 | RESISTOR, European symbol | T
R2 | nb | R-EU_R1206 | R1206 | RESISTOR, European symbol | T
R18 | 100 | R-EU_R1206 | R1206 | RESISTOR, European symbol | T
R22 | nb/100 | R-EU_R1206 | R1206 | RESISTOR, European symbol | T
R43 | nb | R-EU_R1206 | R1206 | RESISTOR, European symbol | T
R45 | nb | R-EU_R1206 | R1206 | RESISTOR, European symbol | T
R47 | nb | R-EU_R1206 | R1206 | RESISTOR, European symbol | T
R65 | nb | R-EU_R1206 | R1206 | RESISTOR, European symbol | T
R66 | nb | R-EU_R1206 | R1206 | RESISTOR, European symbol | T
TP1 | TESTPOINT | TESTPOINT | TESTPOINT | Simple Testpoint for scope probe | T
TP2 | TESTPOINT | TESTPOINT | TESTPOINT | Simple Testpoint for scope probe | T
TP3 | TESTPOINT | TESTPOINT | TESTPOINT | Simple Testpoint for scope probe | T
TP4 | TESTPOINT | TESTPOINT | TESTPOINT | Simple Testpoint for scope probe | T
TP5 | TESTPOINT | TESTPOINT | TESTPOINT | Simple Testpoint for scope probe | T
TP6 | TESTPOINT | TESTPOINT | TESTPOINT | Simple Testpoint for scope probe | T
TP7 | TESTPOINT | TESTPOINT | TESTPOINT | Simple Testpoint for scope probe | T
TP8 | TESTPOINT | TESTPOINT | TESTPOINT | Simple Testpoint for scope probe | T
TP9 | TESTPOINT | TESTPOINT | TESTPOINT | Simple Testpoint for scope probe | T
TP10 | TESTPOINT | TESTPOINT | TESTPOINT | Simple Testpoint for scope probe | T
TP11 | TESTPOINT | TESTPOINT | TESTPOINT | Simple Testpoint for scope probe | T
TP12 | TESTPOINT | TESTPOINT | TESTPOINT | Simple Testpoint for scope probe | T
TP13 | TESTPOINT | TESTPOINT | TESTPOINT | Simple Testpoint for scope probe | T
TP14 | TESTPOINT | TESTPOINT | TESTPOINT | Simple Testpoint for scope probe | T
TP15 | TESTPOINT | TESTPOINT | TESTPOINT | Simple Testpoint for scope probe | T
TP16 | TESTPOINT | TESTPOINT | TESTPOINT | Simple Testpoint for scope probe | T
TP17 | TESTPOINT | TESTPOINT | TESTPOINT | Simple Testpoint for scope probe | T
TP18 | TESTPOINT | TESTPOINT | TESTPOINT | Simple Testpoint for scope probe | T
TP19 | TESTPOINT | TESTPOINT | TESTPOINT | Simple Testpoint for scope probe | T
TP20 | TESTPOINT | TESTPOINT | TESTPOINT | Simple Testpoint for scope probe | T
TP21 | TESTPOINT | TESTPOINT | TESTPOINT | Simple Testpoint for scope probe | T
TP22 | TESTPOINT | TESTPOINT | TESTPOINT | Simple Testpoint for scope probe | T
TP23 | TESTPOINT | TESTPOINT | TESTPOINT | Simple Testpoint for scope probe | T
TP24 | TESTPOINT | TESTPOINT | TESTPOINT | Simple Testpoint for scope probe | T
TP25 | TESTPOINT | TESTPOINT | TESTPOINT | Simple Testpoint for scope probe | T

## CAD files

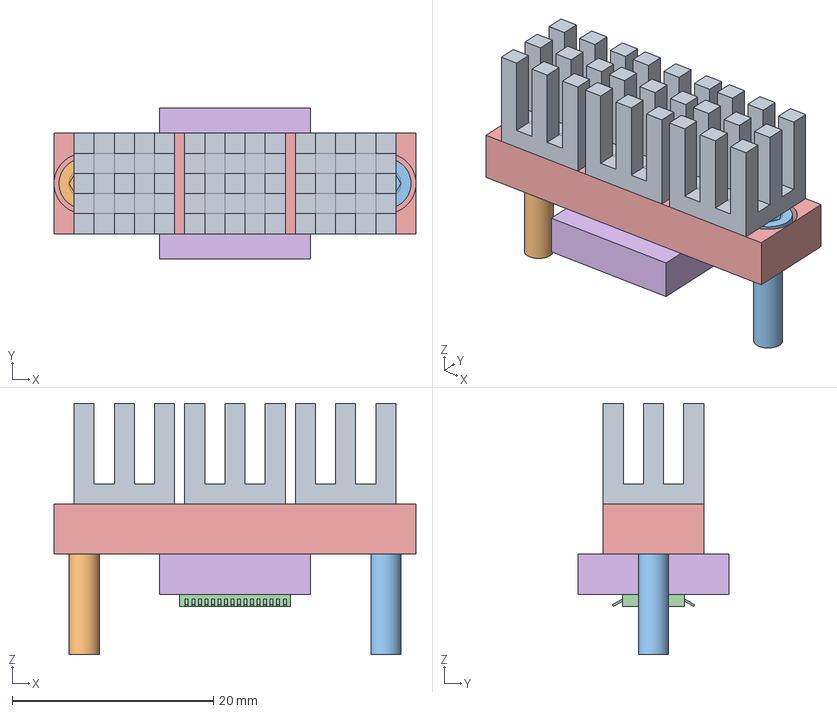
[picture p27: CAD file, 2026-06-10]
fertigungsdaten/Konstruktion-FreeCAD/mark2_kuehlkoerper.FCStd
36.0 x 15.0 x 25.0 mm
Standard-Kuehlkoerper
M3-Schraube1
M3-Schraube2
TAS5828
Block
Waermeleit-Schaum

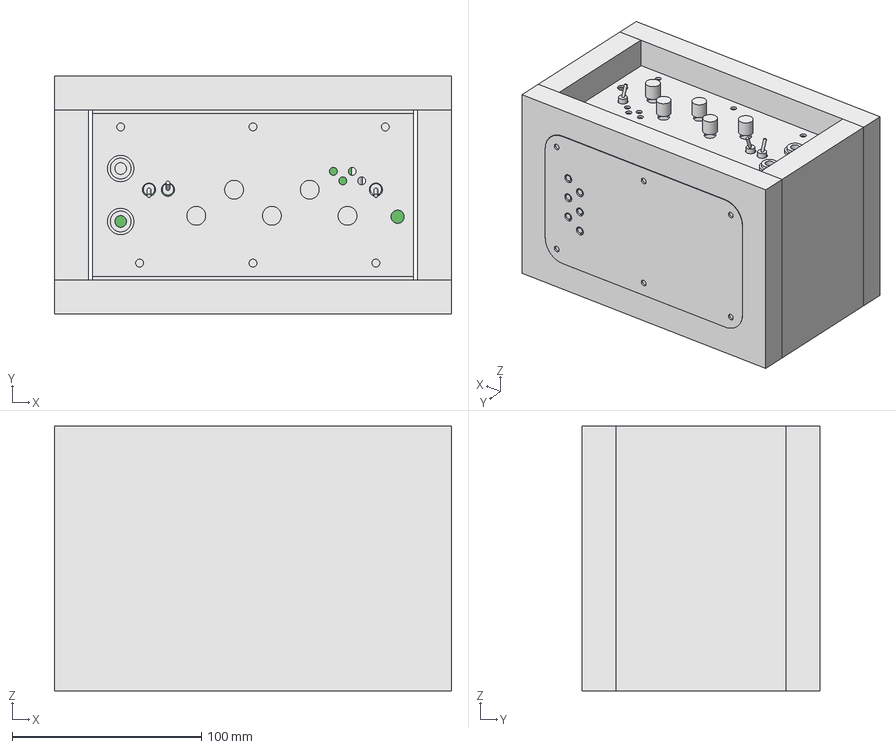
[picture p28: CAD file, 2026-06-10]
fertigungsdaten/Konstruktion-FreeCAD/gehäuse.FCStd
210.0 x 126.0 x 140.0 mm
Board_outline
Board_outline002
Board_outline003
Poti-Knöpfe
Schalter
Klinke-groß001
Klinken
Klinke-Oben

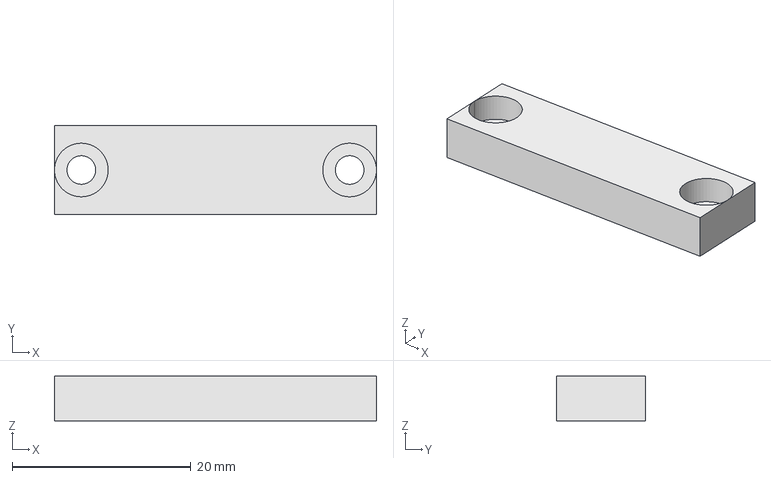
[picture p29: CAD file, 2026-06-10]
fertigungsdaten/Konstruktion-FreeCAD/kuehlkoerper-Block.step
36.0 x 10.0 x 5.00 mm

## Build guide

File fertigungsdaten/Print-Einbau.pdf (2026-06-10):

Print einbauen

Print ist schon mit der vorderen Blende verschraubt … zweite Klinkenbuchse (Switchcraft Inc. 111X, DigiKey-Teilenr. SC2830-ND) wird mit den angelöteten Kabeln mit der Steckklemme verbunden.
Anmerkung: Die vorderen Poti-Knöpfe könnten schon vor dem Einbau ins Gehäuse montiert werden, da die Potis noch leichter zugänglich sind.

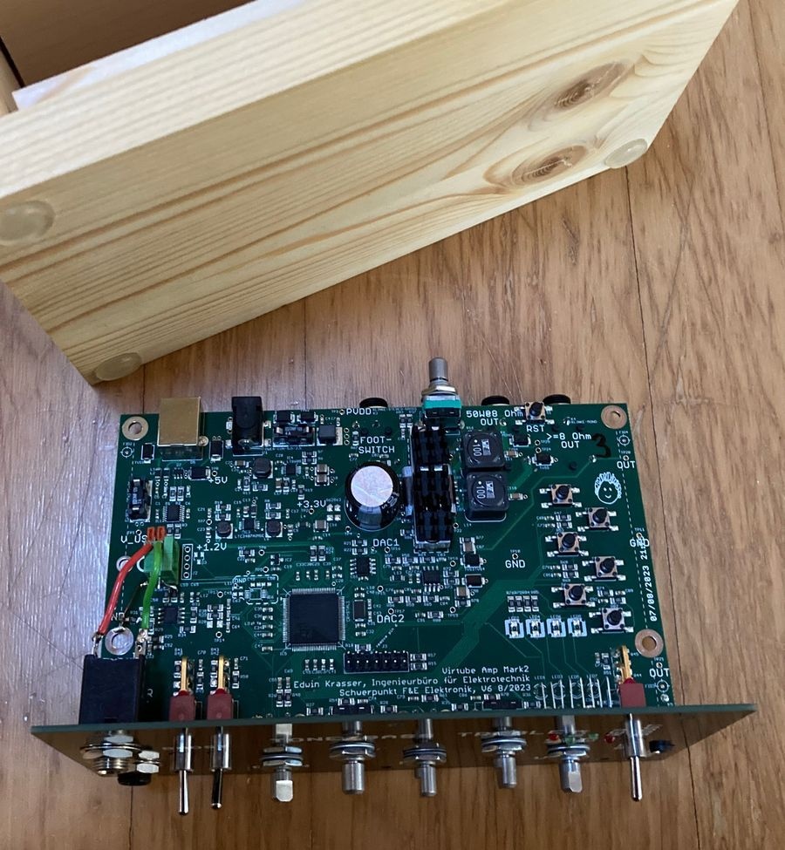
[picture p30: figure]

Print/Vorderblende anschrauben (mit vier Schrauben) …

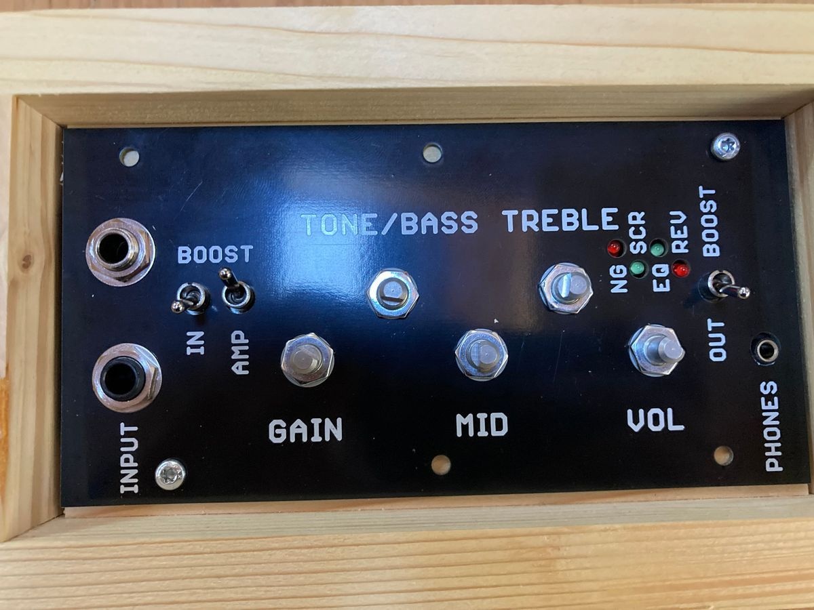
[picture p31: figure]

Tastenstößel überprüfen … (das Flachbandkabel für da Debug-Interface gibt es nur bei meiner Entwickler-Version)

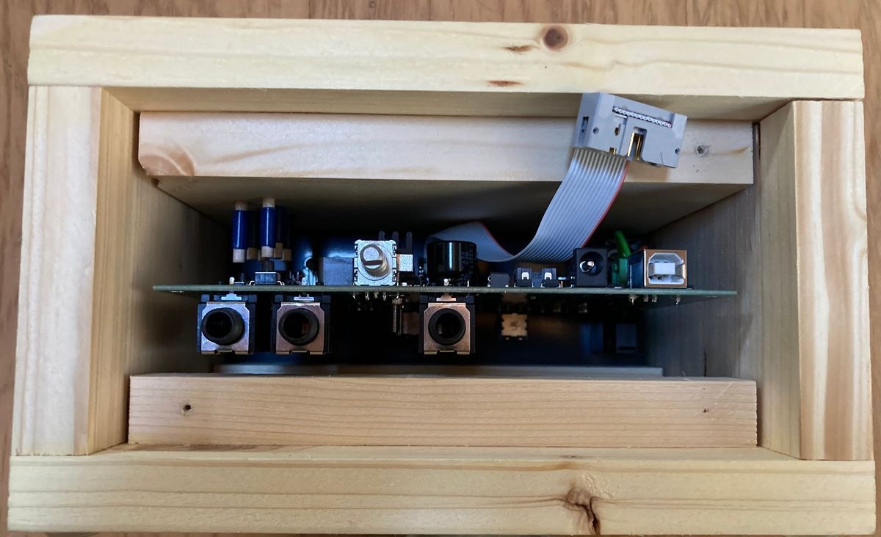
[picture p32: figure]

Hintere Blende anschrauben …

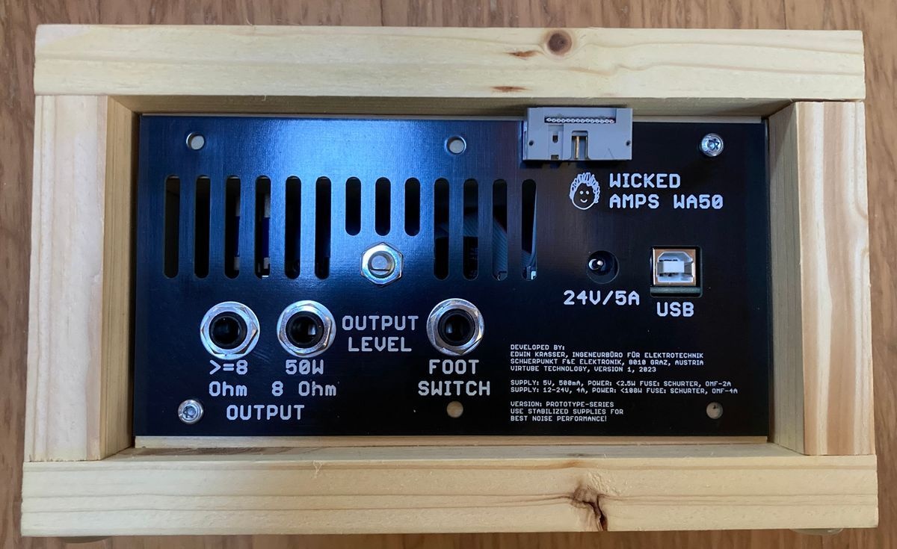
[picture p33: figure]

… Muttern und Potiknöpfe hinauf schrauben …
Anmerkung: Poti-Knöpfe nicht zu tief hinauf stecken und anschrauben, da dann das Drücken nicht mehr geht.

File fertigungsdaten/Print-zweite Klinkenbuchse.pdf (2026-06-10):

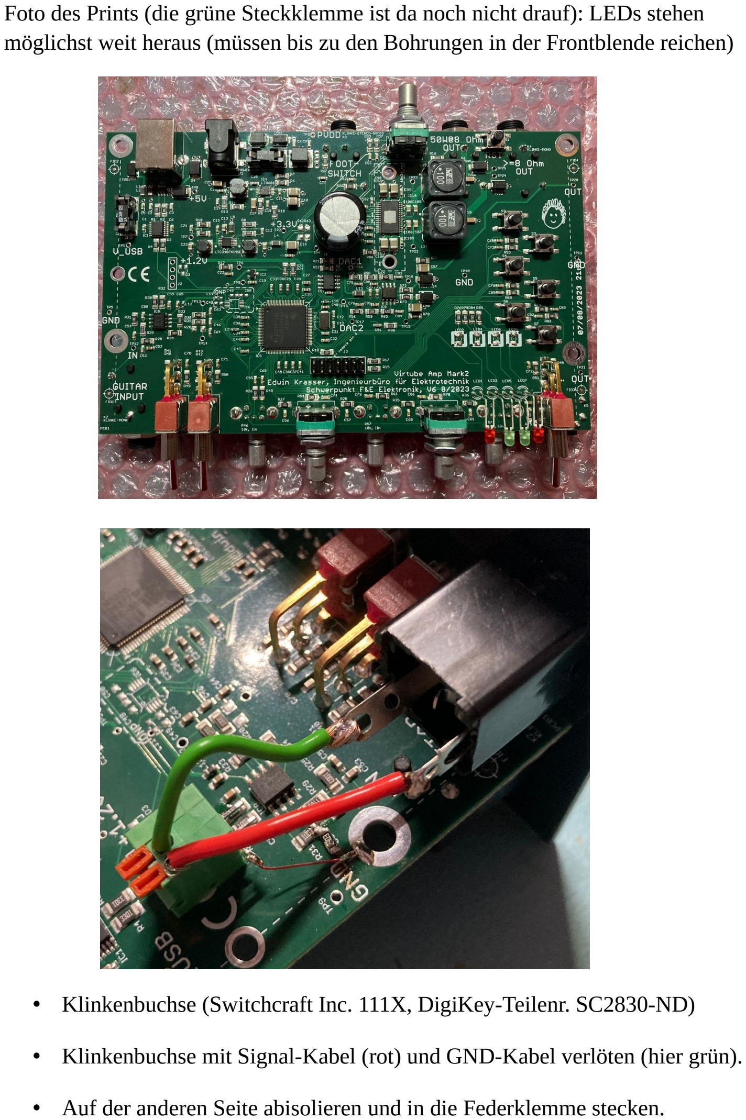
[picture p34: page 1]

Foto des Prints (die grüne Steckklemme ist da noch nicht drauf): LEDs stehen möglichst weit heraus (müssen bis zu den Bohrungen in der Frontblende reichen)

- Klinkenbuchse (Switchcraft Inc. 111X, DigiKey-Teilenr. SC2830-ND)
- Klinkenbuchse mit Signal-Kabel (rot) und GND-Kabel verlöten (hier grün).
- Auf der anderen Seite abisolieren und in die Federklemme stecken.

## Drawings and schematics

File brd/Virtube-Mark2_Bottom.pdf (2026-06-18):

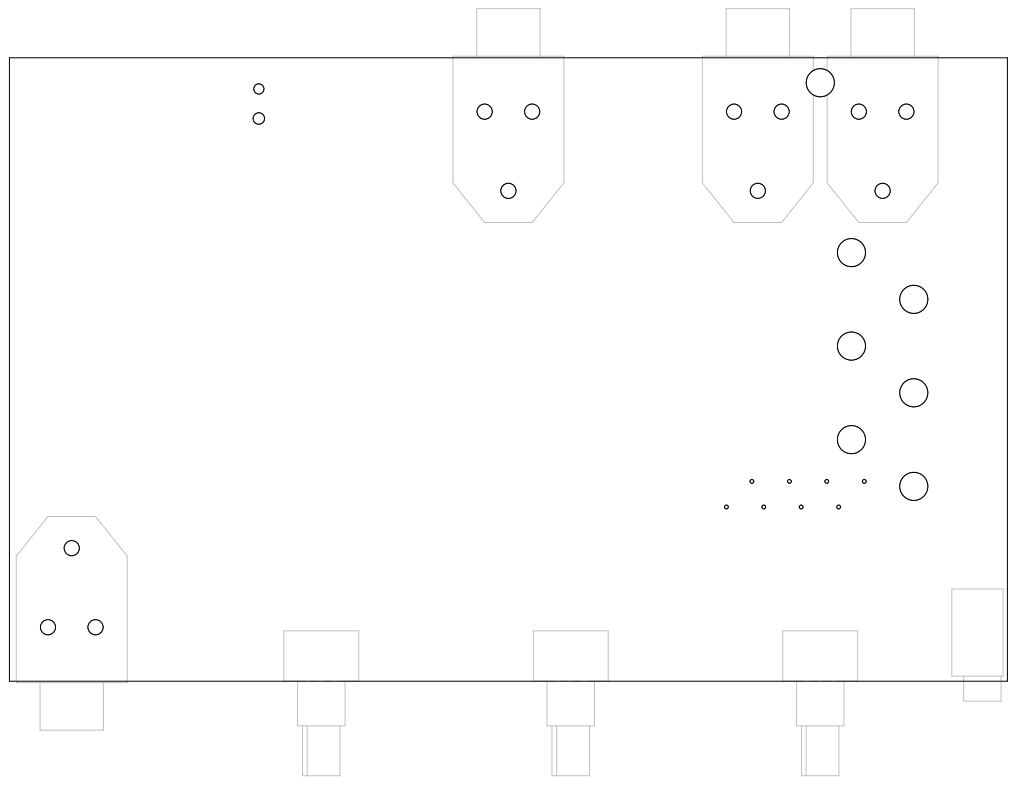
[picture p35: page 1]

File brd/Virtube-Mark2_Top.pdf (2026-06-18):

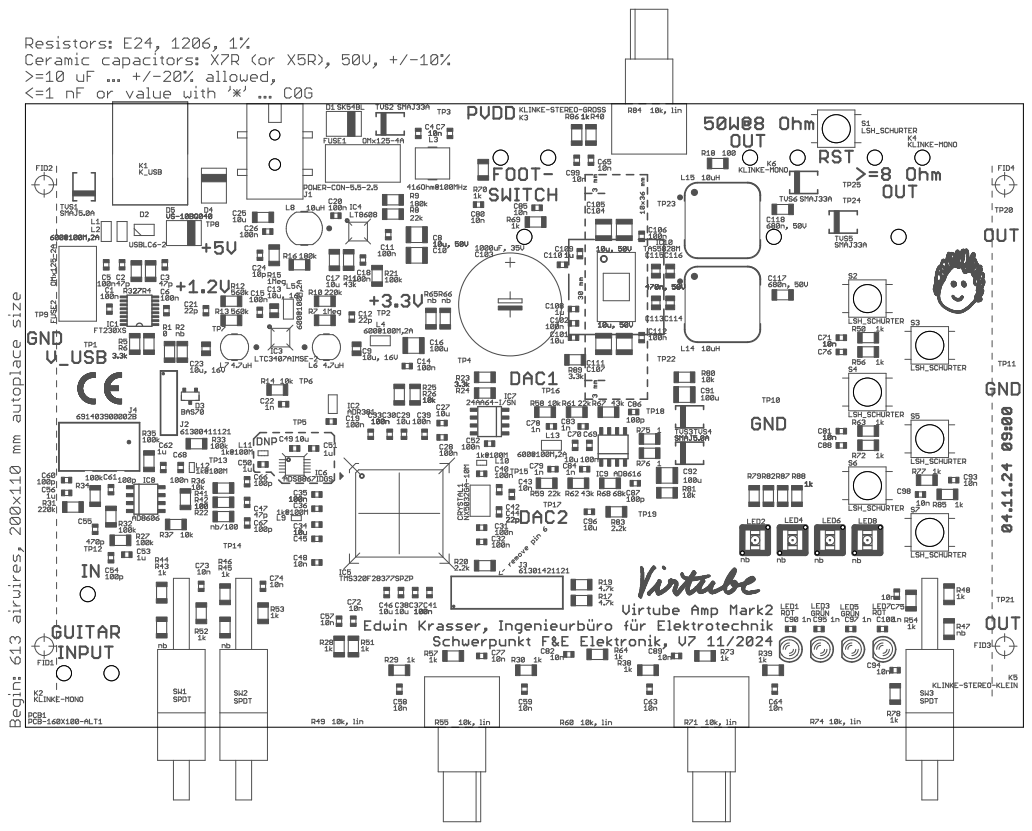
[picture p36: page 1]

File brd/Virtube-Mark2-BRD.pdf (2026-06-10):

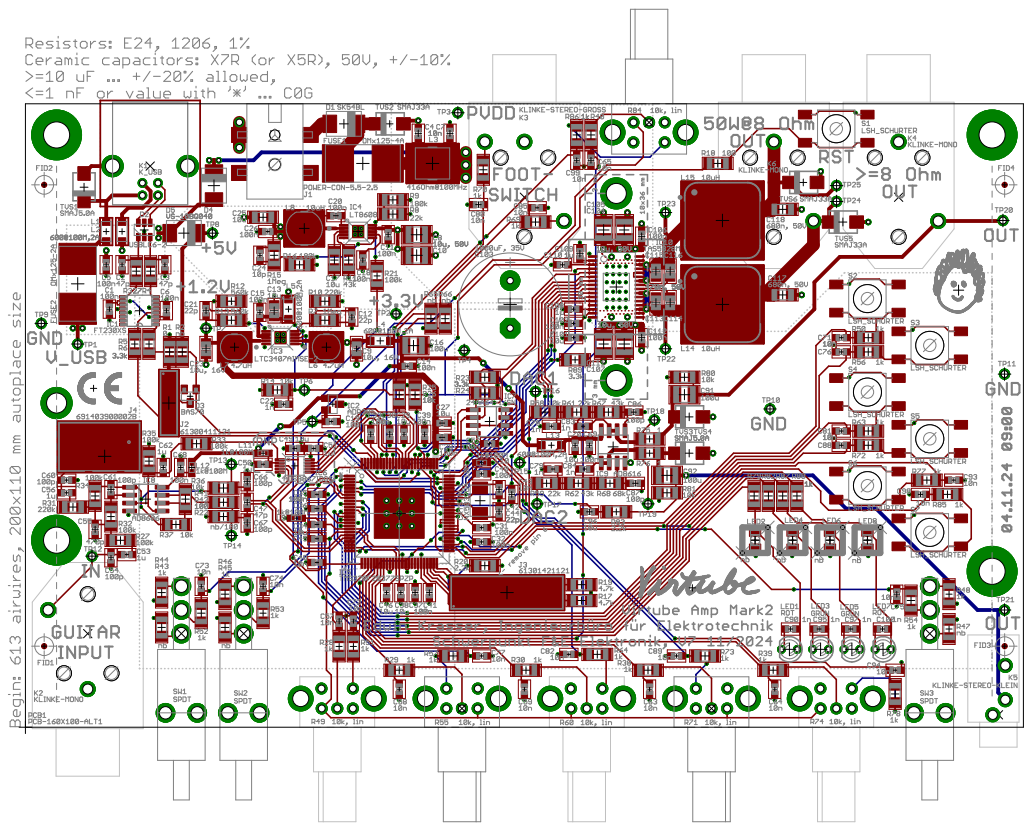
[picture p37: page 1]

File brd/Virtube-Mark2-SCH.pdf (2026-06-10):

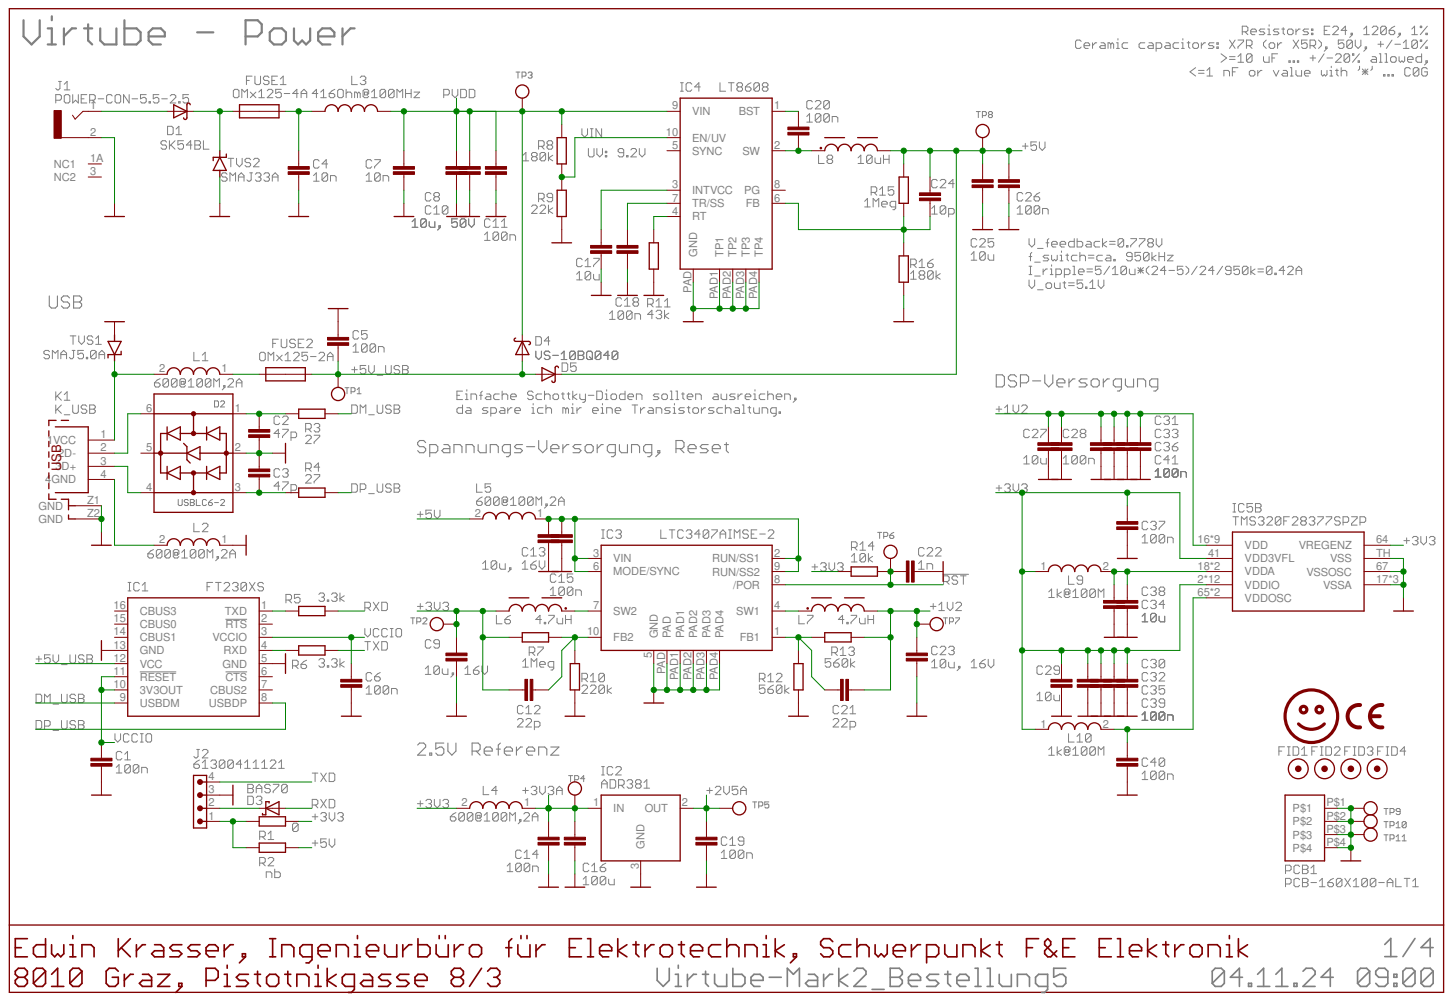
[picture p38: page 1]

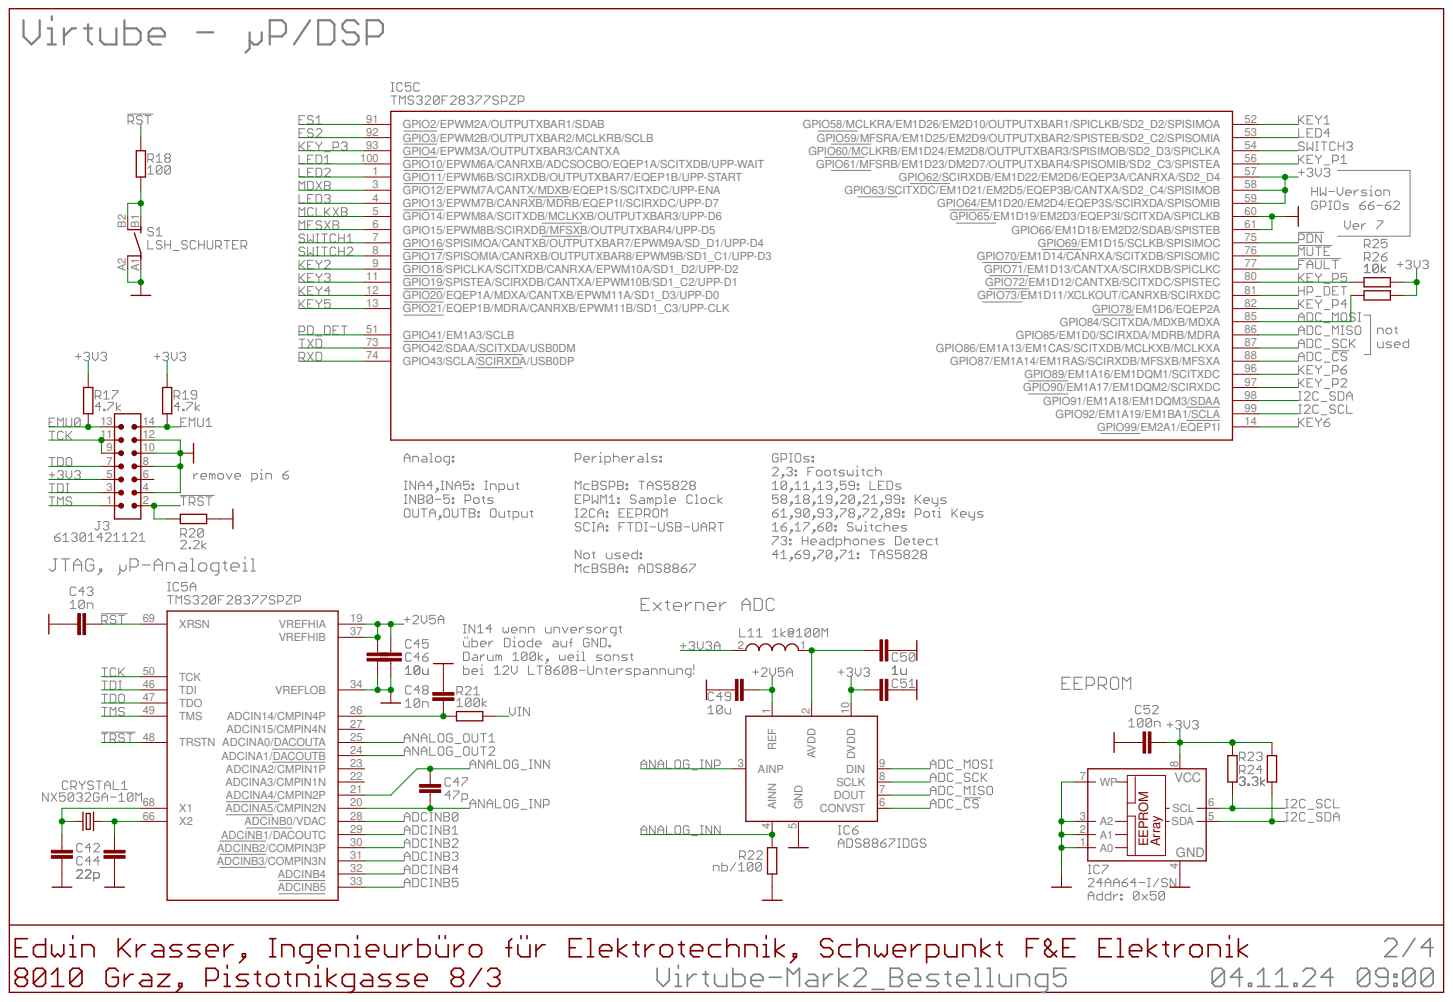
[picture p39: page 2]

GPIO10/EPWM6A/CANRXB/ADCSOCBO/EQEP1A/SCITXDB/UPP-WAIT

8 | 75 GPIO70/EM1D14/CANRXA/SCITXDB/SPISOMIC 76

9 | 77 GPIO72/EM1D12/CANTXB/SCITXDC/SPISTEC

GPIO18/SPICLKA/SCITXDB/CANRXA/EPWM10A/SD1_D2/UPP-D2
GPIO19/SPISTEA/SCIRXDB/CANTXA/EPWM10B/SD1_C2/UPP-D1

85 GPIO85/EM1D0/SCIRXDA/MDRB/MDRA 86

73 | 87 GPIO87/EM1A14/EM1RAS/SCIRXDB/MFSXB/MFSXA
74 | 88

11 | | 12
9 | | 10

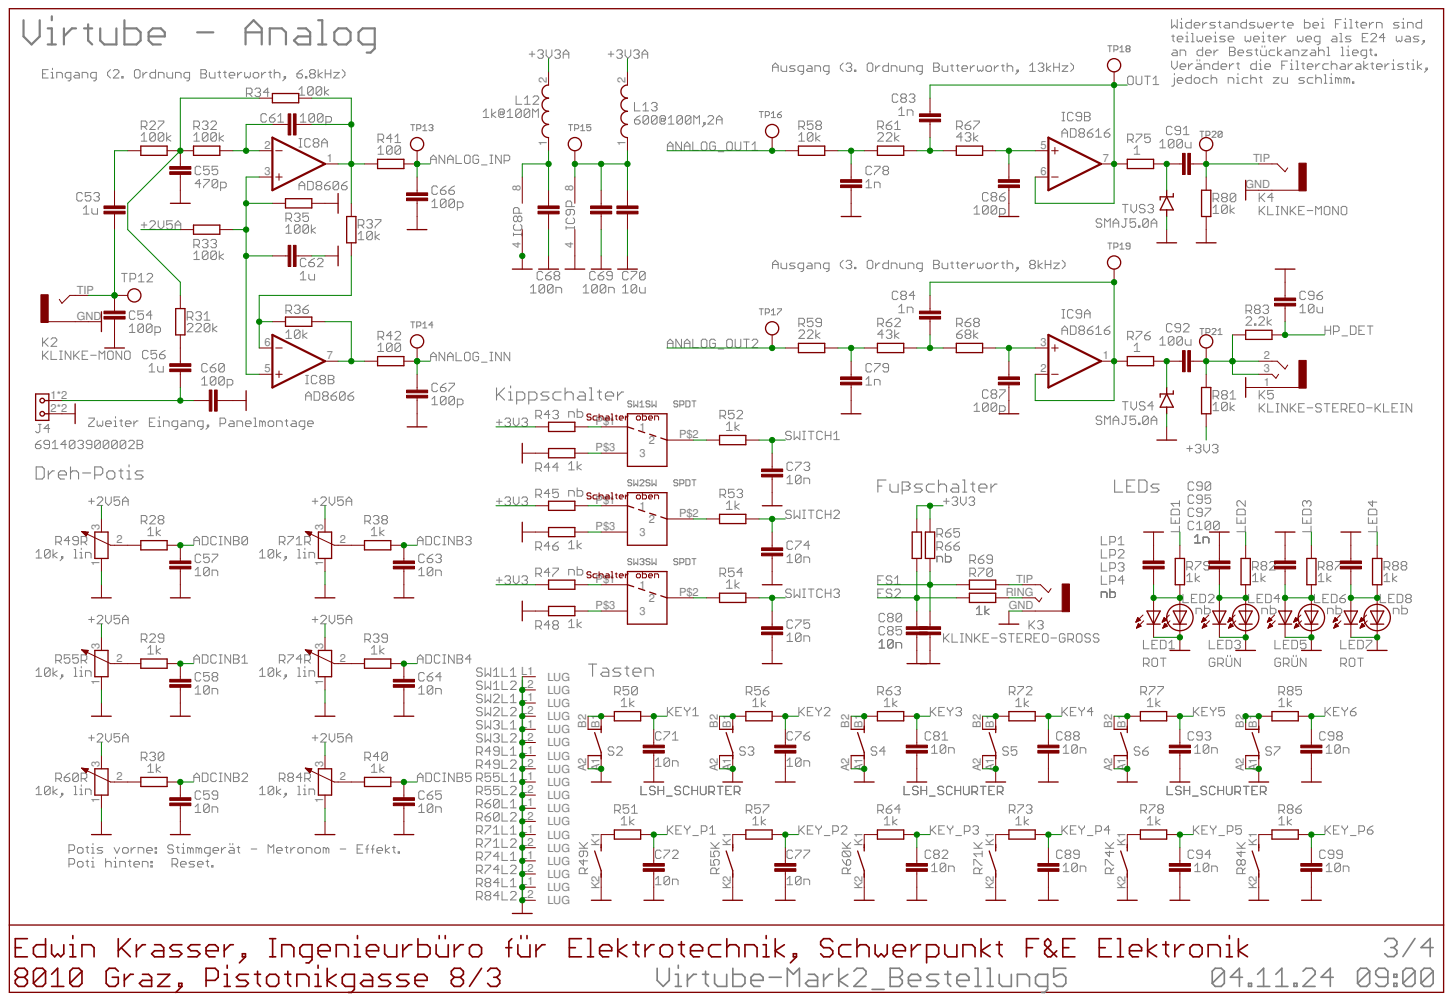
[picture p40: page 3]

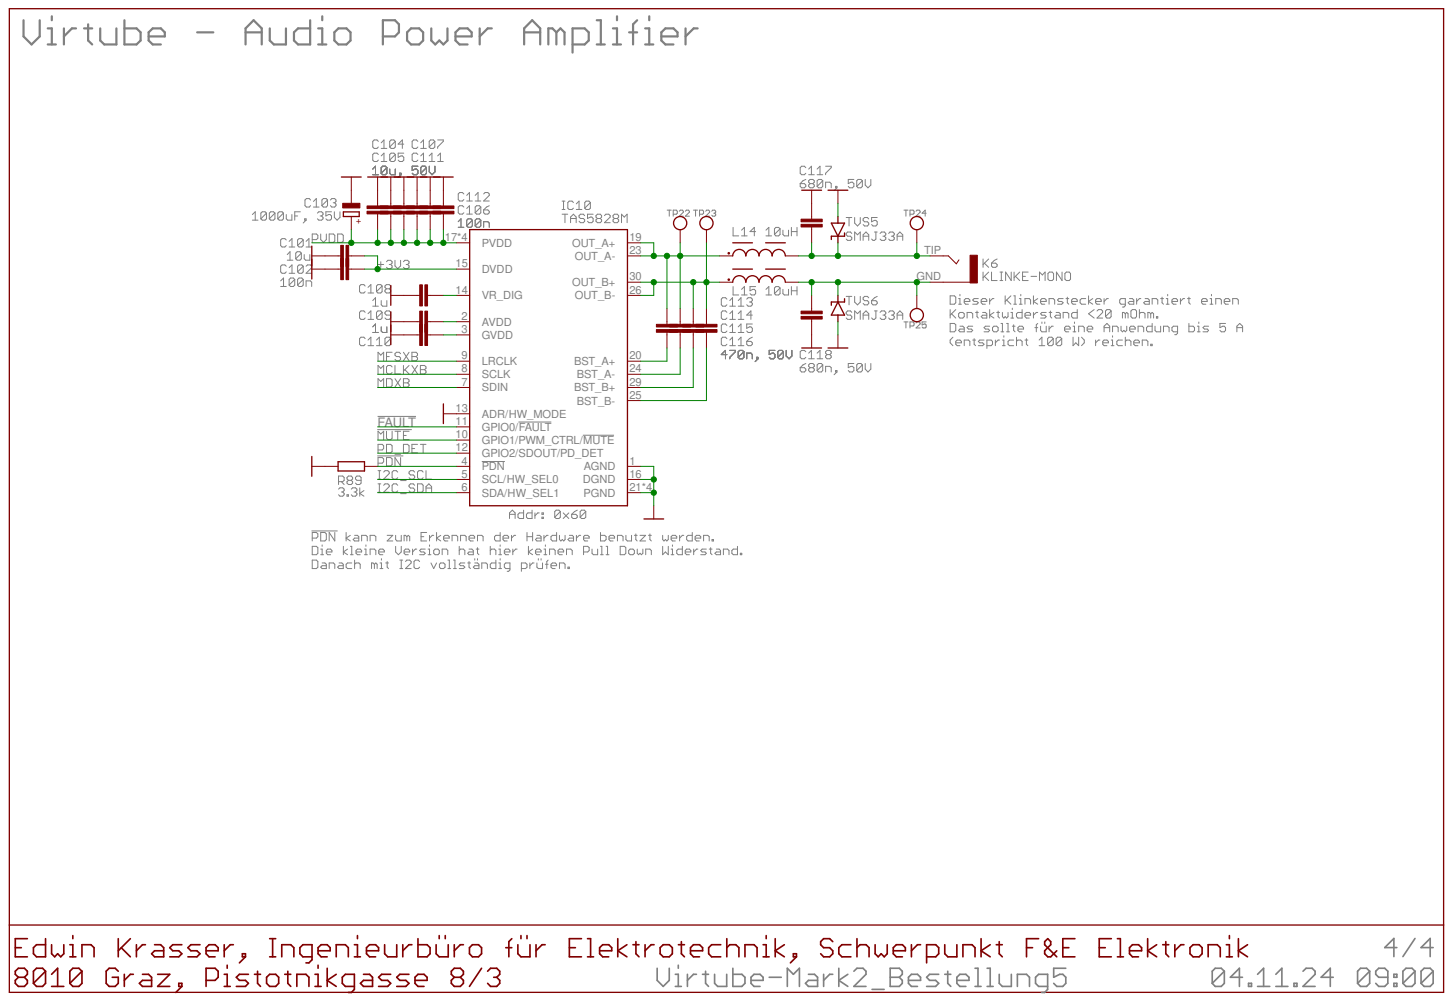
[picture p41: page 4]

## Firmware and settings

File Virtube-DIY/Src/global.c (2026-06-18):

/** @file global.c
  * contains globally used values and functions
  *
  * standard configuration of dsp: PLL factor max, high speed and low speed clock at full speed
  *
  * @author Edwin Krasser, Ingenieurb&uuml;ro f&uuml;r Elektrotechnik, Schwerpunkt F&amp;E Elektronik
  * @version 1.0
  *
  * Virtube – Non-Commercial License
  * Copyright © 2025 Edwin Krasser (ib.ekrasser@gmail.com)
  *
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
  * **Commercial use is explicitly prohibited**, including but not limited to:
  * - sale of the Software or derivatives
  * - incorporation into commercial products
  * - production or distribution for profit
  * - any revenue-generating activity
  *
  * For any commercial licensing, distribution or use inquiries, please contact:
  * ib.ekrasser@gmail.com
  *
  * THE SOFTWARE IS PROVIDED "AS IS", WITHOUT WARRANTY OF ANY KIND, EXPRESS OR
  * IMPLIED, INCLUDING BUT NOT LIMITED TO THE WARRANTIES OF MERCHANTABILITY,
  * FITNESS FOR A PARTICULAR PURPOSE AND NONINFRINGEMENT. IN NO EVENT SHALL THE
  * AUTHORS OR COPYRIGHT HOLDERS BE LIABLE FOR ANY CLAIM, DAMAGES OR OTHER
  * LIABILITY, WHETHER IN AN ACTION OF CONTRACT, TORT OR OTHERWISE, ARISING FROM,
  * OUT OF OR IN CONNECTION WITH THE SOFTWARE OR THE USE OR OTHER DEALINGS IN
  * THE SOFTWARE. */

#ifndef __GLOBAL_C_INCLUDED
#define __GLOBAL_C_INCLUDED

/* declare all DSP28 registers and include C28 specific declarations */
#include "F2837xS_device.h"

/** oscillator frequency */
#define OSC_FREQ   10000000L
/** cpu clock frequency */
#define CLK_FREQ   (OSC_FREQ*20)
/** cpu low speed clock frequency (full speed, 1/2 is reset value) */
#define LSCLK_FREQ (CLK_FREQ)

/** part id */
#define PART_ID     (*(unsigned i32 int *)0x0005D00A)
/** revision id */
#define REV_ID      (*(unsigned i32 int *)0x0005D00C)
/** unique id */
#define UNIQUE_ID   (*(unsigned i32 int *)0x000703CC)

/* macros */

/** pi */
#define PI       3.141592654
/** ln(10) */
#define LN10     2.302585093
/** 2^32 */
#define TWOPOW32 4294967296.0
/** sqrt(2) */
#define SQRT2    1.414213562
/** 2^(1/12) */
#define TWOPOW1DIV12 1.05946
/** square */
#define SQR(a)   ((a)*(a))
/** cube */
#define CUBE(a)  ((a)*(a)*(a))
/** minimum */
#define MIN(a,b) ((a)<(b)? (a):(b))
/** maximum */
#define MAX(a,b) ((a)>(b)? (a):(b))
/** limiter macro */
#define LIMIT(x,Min,Max)  (((x)<(Min))? (Min):((x)>(Max))? (Max):(x))
/** integer limiter macro */
#define ILIMIT(x,Min,Max) __IQsat(x,Max,Min)
/** error value */
#define ERRORVAL          -1000
/** error check */
#define ERROR(x,Min,Max)  (((x)<(Min))? ERRORVAL:((x)>=ERRORVAL)? ERRORVAL:(x))
/** delay loop
  * @param Loops delay in loops */
#define DELAY_LOOP(Loops) { volatile long int i; for(i=0;i<(Loops);i++); }
/** 16 bit int modifier */
#define i16 short
/** 32 bit int modifier */
#define i32 long
/** 64 bit int modifier */
#define i64 long long
/** never execute this line */
#define NEVER if (0)
/** no operation */
#define NOP()    asm(" NOP")
/** wait a very short time */
#define WAIT10() asm(" rpt #9 || NOP")
/** wait a short time */
#define WAIT()   asm(" rpt #255 || NOP")

/** enables interrupts (with depth control) */
#define G_EINT { G_IntDisDepth--; if (G_IntDisDepth<=0) { G_IntDisDepth=0; EINT; } }
/** disables interrupts (with depth control) */
#define G_DINT { G_IntDisDepth++; DINT; }
/** start idling */
#define G_IDLE asm(" IDLE");

/** global ticker */
#define G_Ticker     CpuTimer0Regs.TIM.all
/** ticks per second of global ticker */
#define G_TickerTPS  CLK_FREQ

/** main */
extern int main(void);

/* global variables */

/** interrupt disable depth */
extern int G_IntDisDepth;

/* functions */

/** unsecures dsp (disable csm, disable watchdog) */
extern void G_Unsecure(void);
/** software reset */
extern void G_SWReset(void);
/** global init function (for hardware and software), enable interrupts later in program
  * @return 0 if ok, != if error occured */
extern void G_Init(void);
/** wait function (using cpu timer0)
  * @param ms waiting time in ms
  *
  * @see CLKS_PER_US */
extern void G_msWait(unsigned long int ms);
/** wait function (using cpu timer0)
  * @param us waiting time in us
  *
  * @see CLKS_PER_US */
extern void G_usWait(unsigned long int us);
/** clocks per micro second */
#define CLKS_PER_US 200
/** wait function (using timer0)
  * @param us waiting time in us
  *
  * @see CLKS_PER_US */
extern void G_SetTimeout(unsigned long int us);
/** checks if timeout
  * @return !=0 if timeout */
extern int G_Timeout();

#ifndef HEADER_GLOBAL

#include <math.h>
/* define all DSP28 registers */
#include "../source/F2837xS_GlobalVariableDefs.c"

int G_IntDisDepth;
/** timeout ticker value */
unsigned long int G_TimeoutValue;

#pragma CODE_SECTION(G_Unsecure,"Flash")
void G_Unsecure(void)
{ /* allow access to protected memory regions */
  EALLOW;
  /* initialize system control registers */
  WdRegs.WDCR.all=0x6F;      /* disable watchdog and clear wdflag */

  DcsmZ1Regs.Z1_CSMKEY0=0xFFFFFFFF;
  DcsmZ1Regs.Z1_CSMKEY1=0xFFFFFFFF;
  DcsmZ1Regs.Z1_CSMKEY2=0xFFFFFFFF;
  DcsmZ1Regs.Z1_CSMKEY3=0xFFFFFFFF;

  DcsmZ2Regs.Z2_CSMKEY0=0xFFFFFFFF;
  DcsmZ2Regs.Z2_CSMKEY1=0xFFFFFFFF;
  DcsmZ2Regs.Z2_CSMKEY2=0xFFFFFFFF;
  DcsmZ2Regs.Z2_CSMKEY3=0xFFFFFFFF;

  /* disable access to protected memory regions */
  EDIS;
}

void G_SWReset(void)
{ EALLOW;
  if (WdRegs.SCSR.bit.WDOVERRIDE==0) WdRegs.SCSR.bit.WDOVERRIDE=0x01;
                             /* allow watchdog registers modification */
  WdRegs.WDCR.all=0x0028;    /* bit 15,14,13,12,11,10,9,8=reserved
                              * bit 7=0: no write to WDFLAG
                              * bit 6=0: enable watchdog
                              * bit 5,4,3=101: allow write to register
                              * bit 2,1,0=000: maximum watchdog clock */
  EDIS;
  DINT;
  /* wait for reset */
  for(;;);
}

#pragma CODE_SECTION(G_Init,"Flash")
void G_Init(void)
{ volatile int i;
  /* intialize hardware */

  /* unsecure dsp in RAM version, begause in flash versions unsecure is called before copying code tu ram */
  G_Unsecure();

  /* allow access to protected memory regions */
  EALLOW;
  /* initialize cpu timer 0 for 32 bit counting */
  CpuSysRegs.PCLKCR0.bit.CPUTIMER0=1;
  CpuTimer0Regs.PRD.all=0xFFFFFFFF;
  CpuTimer0Regs.TPR.bit.TDDR=0;
  CpuTimer0Regs.TPRH.bit.TDDRH=0;
  CpuTimer0Regs.TCR.all=0x8020; /* bit 15=1: clear interrupt flag
                                 * bit 14=0: disable cpu timer 0 interrupt
                                 * bit 13,12=reserved
                                 * bit 11,10=00: stop immediately on emulation suspend
                                 * bit 9,8,7,6=reserved
                                 * bit 5=1: reload timer
                                 * bit 4=0: start timer
                                 * bit 3,2,1,0=reserved */
  /* disable and clear interrupts */
  DINT;       /* disable all interrupts */
  IER=0x0000; /* clear all interrupts */
  IFR=0x0000;

  /* initialize PIE control registers */
  PieCtrlRegs.PIECTRL.bit.ENPIE=1;
  PieCtrlRegs.PIEACK.all=0xFFFF;
  /* use external crystal oscillator and turn off internal oscillator */
  ClkCfgRegs.CLKSRCCTL1.bit.XTALOFF=0;      /* turn on XTALOSC */
  ClkCfgRegs.CLKSRCCTL1.bit.OSCCLKSRCSEL=1; /* Clk Src = XTAL */

  ClkCfgRegs.SYSPLLCTL1.bit.PLLCLKEN=0;
  asm(" rpt #20 || nop");
  ClkCfgRegs.SYSCLKDIVSEL.bit.PLLSYSCLKDIV=0;
  /* Lock the PLL five times. This helps ensure a successful start. */
  for(i=0;i<5;i++)
  { ClkCfgRegs.SYSPLLCTL1.bit.PLLEN=0;        /* Turn off PLL */
    asm(" rpt #20 || nop");
    ClkCfgRegs.SYSPLLMULT.all=0x0014;         /* Write multiplier, which automatically turns on the PLL */
    while(ClkCfgRegs.SYSPLLSTS.bit.LOCKS!=1); /* Wait for the SYSPLL lock counter */
  }
  /* low speed clock at full speed */
  ClkCfgRegs.LOSPCP.bit.LSPCLKDIV=0;

  /* some stuff copied from the InitSysPLL function of the examples */
  ClkCfgRegs.SYSCLKDIVSEL.bit.PLLSYSCLKDIV=1;
  DevCfgRegs.SYSDBGCTL.bit.BIT_0=1;
  ClkCfgRegs.SYSPLLCTL1.bit.PLLCLKEN=1;
  asm(" RPT #20 || NOP");
  DevCfgRegs.SYSDBGCTL.bit.BIT_0 = 0;
  asm(" RPT #200 || NOP");
  ClkCfgRegs.SYSCLKDIVSEL.bit.PLLSYSCLKDIV=0;

  /* enable all pull up resistors */
  GpioCtrlRegs.GPAPUD.all=
  GpioCtrlRegs.GPBPUD.all=
  GpioCtrlRegs.GPCPUD.all=
  GpioCtrlRegs.GPDPUD.all=0;

  /* finish hardware setup */
  EDIS; /* disable access to protected memory regions */
        /* enable all interrupts later in program */

  /* interrupts disable */
  G_IntDisDepth=0;
  G_DINT;
}

void G_usWait(unsigned long int us)
{ unsigned long int StopTime;

  asm(" clrc ovm");
  StopTime=CpuTimer0Regs.TIM.all-((unsigned long int)CLKS_PER_US)*us;
  while((signed long int)(CpuTimer0Regs.TIM.all-StopTime)>0);
}

void G_msWait(unsigned long int ms)
{ G_usWait(1000*ms);
}

void G_SetTimeout(unsigned long int us)
{ asm(" clrc ovm");
  G_TimeoutValue=G_Ticker-CLKS_PER_US*us;
}

int G_Timeout()
{ return((signed long int)(G_Ticker-G_TimeoutValue)<0);
}

#else
#undef HEADER_GLOBAL
#endif

#endif

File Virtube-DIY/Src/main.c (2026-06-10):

/** @file main.c
  * the main program skeleton
  *
  * @author Edwin Krasser, Ingenieurb&uuml;ro f&uuml;r Elektrotechnik, Schwerpunkt F&amp;E Elektronik
  * @version 0.9
  *
  * Virtube – Non-Commercial License
  * Copyright © 2025 Edwin Krasser (ib.ekrasser@gmail.com)
  *
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
  * **Commercial use is explicitly prohibited**, including but not limited to:
  * - sale of the Software or derivatives
  * - incorporation into commercial products
  * - production or distribution for profit
  * - any revenue-generating activity
  *
  * For any commercial licensing, distribution or use inquiries, please contact:
  * ib.ekrasser@gmail.com
  *
  * THE SOFTWARE IS PROVIDED "AS IS", WITHOUT WARRANTY OF ANY KIND, EXPRESS OR
  * IMPLIED, INCLUDING BUT NOT LIMITED TO THE WARRANTIES OF MERCHANTABILITY,
  * FITNESS FOR A PARTICULAR PURPOSE AND NONINFRINGEMENT. IN NO EVENT SHALL THE
  * AUTHORS OR COPYRIGHT HOLDERS BE LIABLE FOR ANY CLAIM, DAMAGES OR OTHER
  * LIABILITY, WHETHER IN AN ACTION OF CONTRACT, TORT OR OTHERWISE, ARISING FROM,
  * OUT OF OR IN CONNECTION WITH THE SOFTWARE OR THE USE OR OTHER DEALINGS IN
  * THE SOFTWARE. */

#include <math.h>
#include <stdlib.h>
#include <string.h>

#define HEADER_ADCDAC
#include "adcdac.c"
#define HEADER_AMPS
#include "amps.c"
#define HEADER_CONSTS
#include "consts.c"
#define HEADER_EQUALIZER
#include "equalizer.c"
#define HEADER_GLOBAL
#include "global.c"
#define HEADER_I2C
#include "i2c.c"
#define HEADER_MISC
#include "misc.c"
#define HEADER_NOISEGATE
#include "noisegate.c"
#define HEADER_NOSPRINTF
#include "nosprintf.c"
#define HEADER_POWERDAC
#include "powerdac.c"
#define HEADER_REVERB
#include "reverb.c"
#define HEADER_SCIA
#include "scia.c"
#define HEADER_TUBESCR
#include "tubescr.c"

/** head phone detect */
#define HEADPHONE_DET      ((GpioDataRegs.GPCDAT.bit.GPIO73==0)? 1:0)
/** headphones flag */
static int HeadphoneFlag;

/** seconds counter */
static unsigned i32 int SecCounter;

/** adc interrupt service routine */
interrupt void AdcIsr(void)
{ float vi;                  /* input value */
  float vo;           /* output value */

  vi=ADC_IN;
  vo=AMPS_Calc(vi);
  vo=LIMIT(vo,-1.24,1.24);

  /* headphone flag check and output */
  if (HeadphoneFlag==0) DAC1_SET(vo*(1/1.25)); else DAC1_SET(0);
  /* set power dac, if there is none, it's no problem */
  if (HeadphoneFlag==0)
  { if(PDAC_Status.bit.V5Mode!=0) vo*=0.57;
    PDAC_SET((int)(vo*(0x7FFF/1.25)));
  } else
    PDAC_SET(0);
  /* headzhone output */
  DAC2_SET(vo*(1/1.25));

  ADC_ACK();
  /* check keys */
  MISC_CheckKeys();
}

/* include the protocol stuff to make the file shorter */
#include "mainprot.c"

void TheMain(void)
{ unsigned i32 int NextTicker1,NextTicker10,NextTicker25;

  /* initialize hardware */
  AD_Init(AdcIsr);
  I2C_Init();
  MISC_Init();
  PDAC_Init();
  AMPS_Init();
  SCIA_Init(115200,EVEN_PARITY);
  /* initialize effects */
  NG_Init();
  TS_Init();
  EQ_Init();
  RV_Init();

  G_EINT;
  SCIA_Transmit("\nVirtube says hello!",0); G_msWait(5);
  /* the main loop */
  for(SecCounter=0,NextTicker1=G_Ticker-CLK_FREQ,NextTicker10=G_Ticker-(CLK_FREQ/10),NextTicker25=G_Ticker-(0.5*CLK_FREQ/25);;)
  { /* idle ... */
    G_IDLE;
    /* poll for uart commands */
  	if (SCIA_Poll()!=NULL) ParseCommand(NULL,NULL);
  
  	/** poll the keys */
  	if (MISC_Keys!=0||MISC_PotiKeys>0)
  	{

      /* clear key press */
      MISC_Keys=MISC_PotiKeys=0;
  	}

    if ((signed long int)(G_Ticker-NextTicker25)<=0)
    { /* 25 times per second ... */

      /* set switches */
  	  AMPS_SetSwitches(SWITCH1|(SWITCH2<<1)|(SWITCH3<<2));
      /* get pots and start poti conversion */
      AD_GetMiscADCs();
      /* set amp parameters */
      AMPS_SetParams(AD_Pots);

      /* wait for 40 ms */
      NextTicker25-=(CLK_FREQ/25);
    }

    if ((signed long int)(G_Ticker-NextTicker10)<=0)
    { 
  

      /* check headphones */
      HeadphoneFlag=HEADPHONE_DET;
      /* check power dac */
      PDAC_Check();

      /* wait for 100 ms */
      NextTicker10-=(CLK_FREQ/10);
    }

    /* once per second */
    if ((signed long int)(G_Ticker-NextTicker1)<=0)
  	{

      SecCounter++;
	    /* update counter */
	    NextTicker1-=CLK_FREQ;
    }
  }
}

extern int RamfuncsLoadStart;
extern int RamfuncsLoadSize;
extern int RamfuncsRunStart;

#pragma CODE_SECTION(main,"Flash")
int main(void)
{ /* global initialization */
  G_Init();
  /* flash to ram copy */
  #ifdef FLASH
  memcpy(&RamfuncsRunStart,&RamfuncsLoadStart,(unsigned i32 int)&RamfuncsLoadSize);
  #endif
  TheMain();
}

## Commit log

2026-06-10 Add files via upload
    Schaltplan, PCB-Layout, Fertigungsdaten.
    [Virtube-Mark2-Parts.xls, Virtube-Mark2.brd, Virtube-Mark2.xls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]
2026-06-10 Add files via upload
    Software Framework ohne TI-Bibliotheken (da Lizenzbedingungen noch nicht klar).
2026-07-20 Update README with example calculation reference
    Added reference to example calculation in amps.c for virtual tube calculation.
